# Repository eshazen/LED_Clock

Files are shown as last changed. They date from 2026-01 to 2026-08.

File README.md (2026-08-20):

# LED Clock

Yet another LED pseudo-analog clock.
<br>6 concentric circles of 60 LEDs plus one of 12 LEDs.
<br>Arduino Nano ESP32.

Current code (`clock_v3`) runs on 1Hz interrupts but expects
periodic time updates of the format `[hh:mm:ss]` at 1200 baud
from an external RTC.

First release code (`clock_v2`) just uses 1Hz timer interrupts
and provides hour / minute set buttons.

No ECOs on the PC board.  Forgot mounting holes though.
See `Case` folder for a two-part 3D printed wall hangar
with a little control panel for the set buttons.

Works OK but loses ~1min/day.  Need to work on the timekeeping.

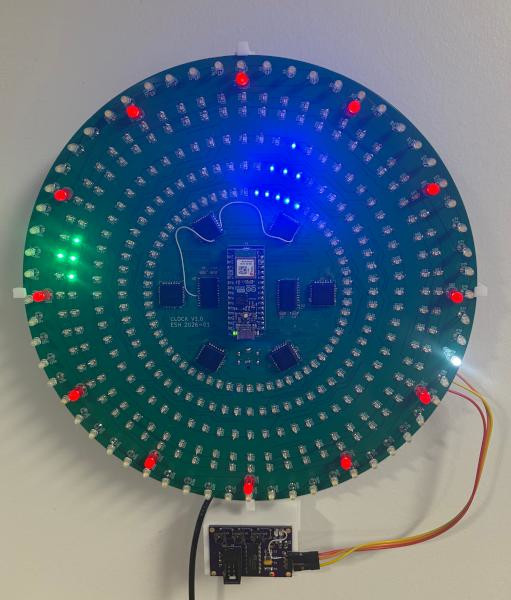
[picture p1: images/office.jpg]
Front View


### 2026-04-19

Implemented initial RTC board software.

### 2026-04-12

Working on SimpleRTC add-on to keep better time.
<br>Need a serial port on the ESP32.
<br>It's confusing:
https://forum.arduino.cc/t/nano-esp32-onboard-uart-and-pin-numbering-issues/1269099/9

I _think_ this should work:

    Serial1.begin(1200, SERIAL_8N1, D11, D12);

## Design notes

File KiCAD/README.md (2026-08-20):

# PCB designs

`Led_clock_sector` is the main PCB.  No errors I'm aware of.
The current version here has mounting holes which are missing
from the V1 as-built version.

`SimpleRTC` is a small board with RTC, MCU and pushbuttons.
The version here in git as of this writing is incomplete...
no doubt there is an un-committed update on a laptop somewhere.

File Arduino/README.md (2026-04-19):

# LED_Clock

New version `clock_v3` expects time-set data at 1200 baud
on D12.  Set string format `[hh:mm:ss]`.
Runs with timer interrups between set commands

Previous sketch `clock_v2` uses
set buttons.  Timekeeping just uses the
ESP32 timer interrupts.  Loses ~1m per day.

`led_test` is useful for debugging LED issues.

`clock_ntp` is an attempt to get the time from NPT
servers but doesn't work reliably.

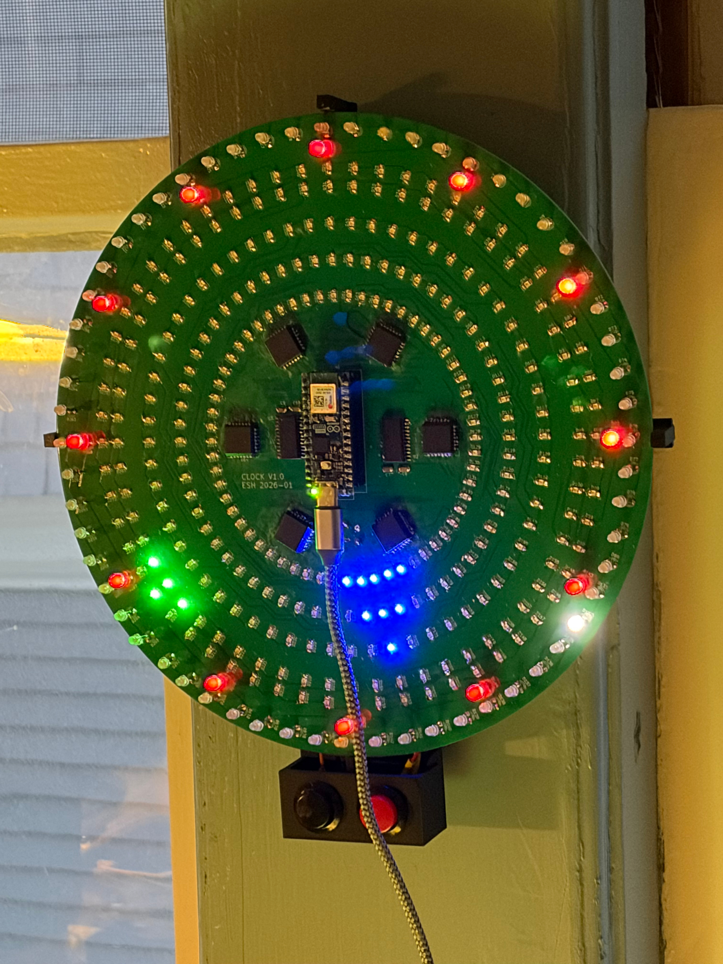
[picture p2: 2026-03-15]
images/front.jpg

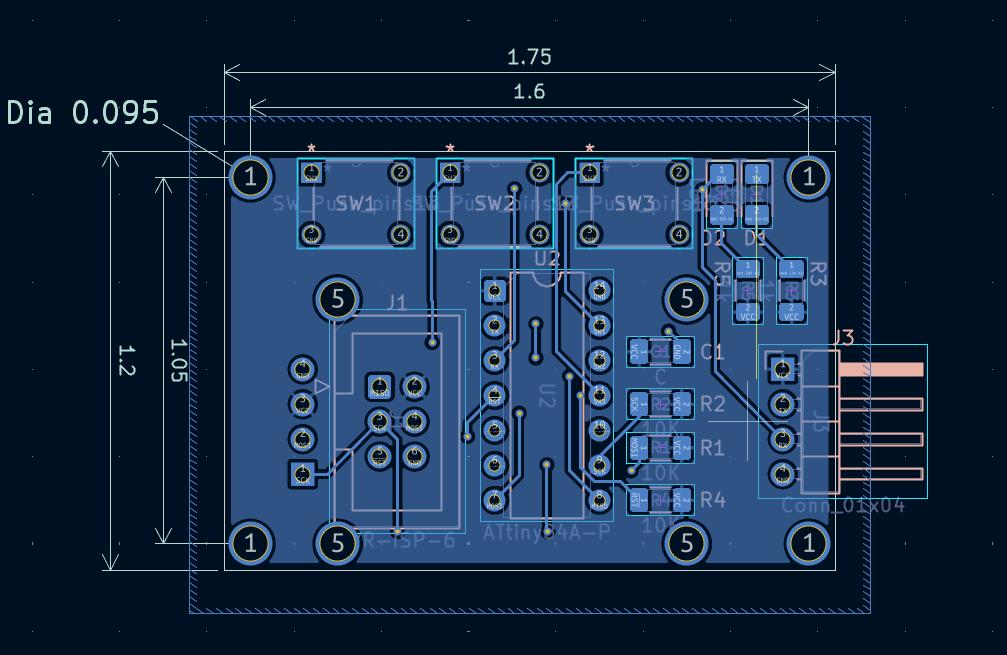
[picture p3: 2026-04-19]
Case/SimpleRTC_V1_Sketch.png

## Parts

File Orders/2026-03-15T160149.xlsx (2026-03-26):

Digi-Key: Shopping Cart
Index | Quantity | Part Number | Manufacturer Part Number | Description | Customer Reference | Available | Backorder | Unit Price | Extended Price USD
1 | 6 | 732-5013-ND | 151033RS03000 | LED RED CLEAR 3MM ROUND T/H | D1,D2 | 6 | 0 | 0.17 | 1.02
2 | 3 | A122759-ND | 1761681-1 | CONN HEADER VERT 6POS 2.54MM | J1 | 3 | 0 | 1.65 | 4.95
3 | 6 | 2057-PH1RB-04-UA-ND | PH1RB-04-UA | CONN HEADER R/A 4POS 2.54MM | J2 | 6 | 0 | 0.16 | 0.96
4 | 3 | ATTINY84A-PU-ND | ATTINY84A-PU | IC MCU 8BIT 8KB FLASH 14DIP | U2 | 3 | 0 | 1.62 | 4.86
5 | 10 | 450-1157-ND | FSM101 | SWITCH TACTILE SPST-NO 0.05A 24V |  | 10 | 0 | 0.382 | 3.82

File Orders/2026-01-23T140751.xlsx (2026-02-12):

Digi-Key: Shopping Cart
Index | Quantity | Part Number | Manufacturer Part Number | Description | Customer Reference | Available | Backorder | Unit Price | Extended Price USD
1 | 10 | 1516-QBL7IW60D-NW-ND | QBL7IW60D-NW | LED WHITE DIFFUSED T-1 T/H |  | 10 | 0 | 0.41 | 4.10
2 | 5 | 732-5016-ND | 151051RS11000 | LED RED DIFFUSED 5MM ROUND T/H |  | 5 | 0 | 0.15 | 0.75
3 | 25 | 3147-B1A81NG--20C000313U1930CT-ND | B1A81NG--20C000313U1930 | LED GREEN CLEAR 1206 SMD |  | 25 | 0 | 0.12 | 3.00
4 | 30 | 3147-B1A81NB--20C000313U1930CT-ND | B1A81NB--20C000313U1930 | LED BLUE CLEAR 1206 SMD |  | 30 | 0 | 0.12 | 3.60

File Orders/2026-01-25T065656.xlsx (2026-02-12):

Digi-Key: Shopping Cart
Index | Quantity | Part Number | Manufacturer Part Number | Description | Customer Reference | Available | Backorder | Unit Price | Extended Price USD
1 | 1 | 1050-ABX00083-ND | ABX00083 | ARDUINO NANO ESP32 WITH HEADERS | A1 | 1 | 0 | 19.3 | 19.30
2 | 25 | 4713-GMC31X7R104K10NTCT-ND | GMC31X7R104K10NT | CAP1206 X7R .1UF 10% 10V | C1,C2,C3,C4,C5,C6,C7,C8,C9,C10 | 25 | 0 | 0.067 | 1.68
3 | 100 | 1516-QBL7IW60D-NW-ND | QBL7IW60D-NW | LED WHITE DIFFUSED T-1 T/H | D1,D2,D3,D4,D5,D6,D7,D8,D9,D10,D71,D72,D73,D74,D | 100 | 0 | 0.2963 | 29.63
4 | 20 | 732-5016-ND | 151051RS11000 | LED RED DIFFUSED 5MM ROUND T/H | D11,D12,D81,D82,D143,D144,D205,D206,D267,D268,D3 | 20 | 0 | 0.15 | 3.00
5 | 140 | 3147-B1A81NG--20C000313U1930CT-ND | B1A81NG--20C000313U1930 | LED GREEN CLEAR 1206 SMD | D21,D22,D23,D24,D25,D26,D27,D28,D29,D30,D31,D32, | 140 | 0 | 0.12 | 16.80
6 | 200 | 3147-B1A81NB--20C000313U1930CT-ND | B1A81NB--20C000313U1930 | LED BLUE CLEAR 1206 SMD | D41,D42,D43,D44,D45,D46,D47,D48,D49,D50,D51,D52, | 200 | 0 | 0.12 | 24.00
7 | 1 | CP-082BHCT-ND | PJ-082BH | CONN PWR JACK 2.5X5.5MM SOLDER | J2 | 1 | 0 | 1.78 | 1.78
8 | 1 | A120356-ND | 1-2199300-2 | CONN IC DIP SOCKET 32POS TINLEAD | N1 | 1 | 0 | 0.92 | 0.92
9 | 10 | ICM7218AIQI+-ND | ICM7218AIQI+ | IC DRVR 7 SEGMNT 8 DIGIT 28PLCC | U1,U51,U52,U53,U54,U55 | 10 | 0 | 12.616 | 126.16
10 | 2 | 296-14911-1-ND | SN74LVC4245ADWR | IC XLTR VL BIDIR 24-SOIC | U2,U3 | 2 | 0 | 1.79 | 3.58

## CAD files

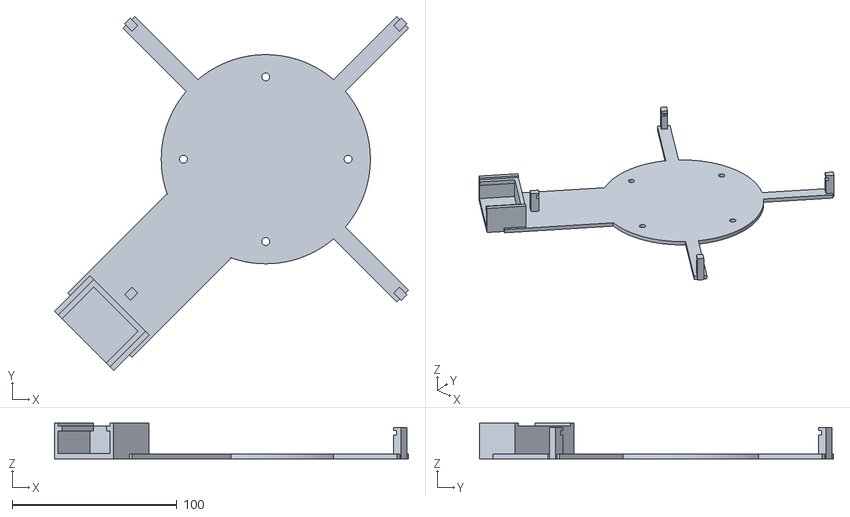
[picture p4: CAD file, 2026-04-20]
Case/plate2.stl
215.0 x 215.0 x 21.6

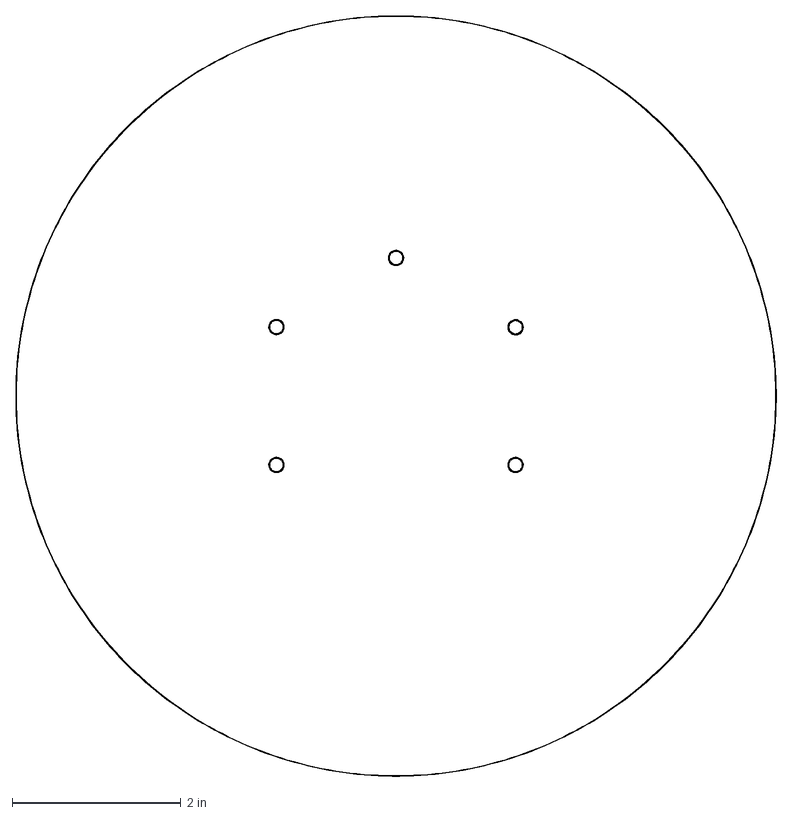
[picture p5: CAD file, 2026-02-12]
KiCAD/Led_clock_sector/DXF/Led_clock_sector-User_3.dxf
9.00 x 9.00 in

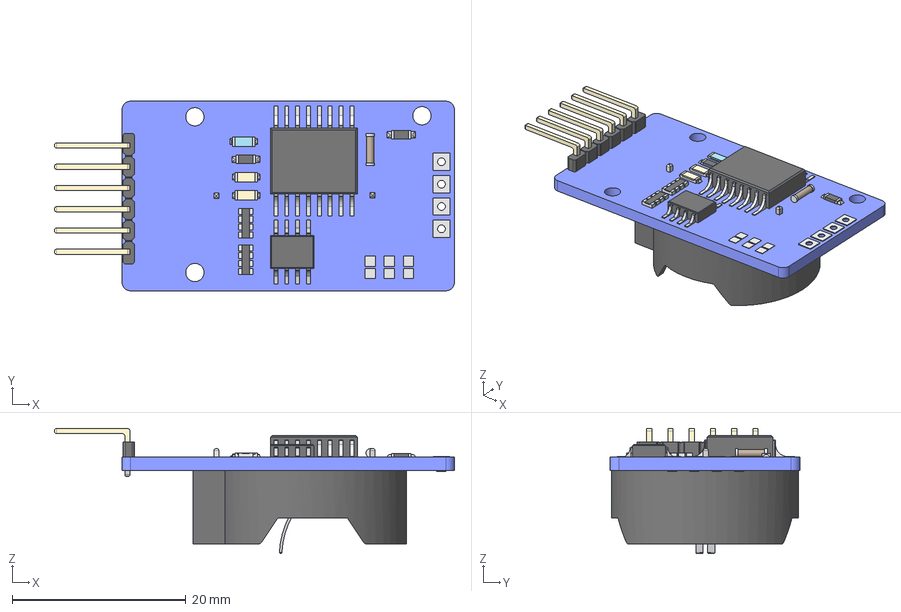
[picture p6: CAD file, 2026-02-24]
KiCAD/SimpleRTC/HW-84 v7.step
46.1 x 21.9 x 14.4 mm

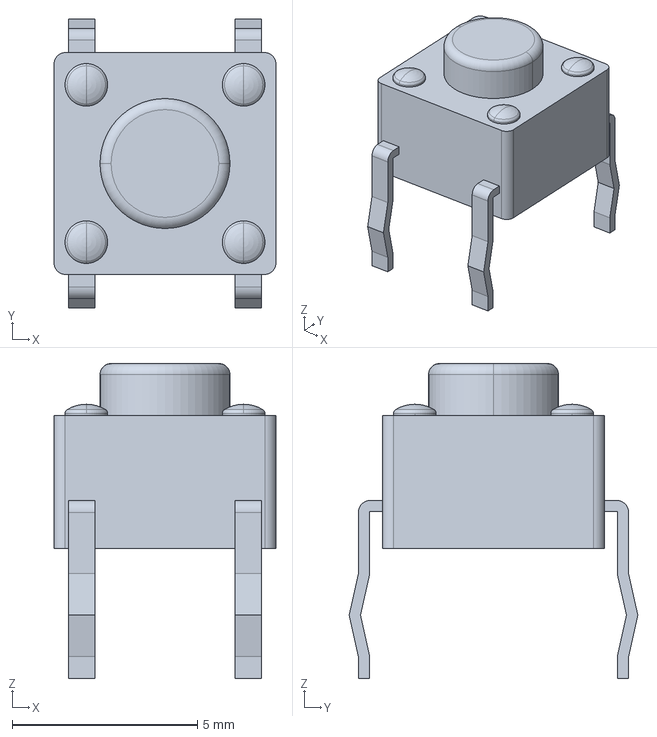
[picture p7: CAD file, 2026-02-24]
KiCAD/SimpleRTC/models/c-1825910-6-c-3d.stp
5.99 x 7.80 x 8.51 mm

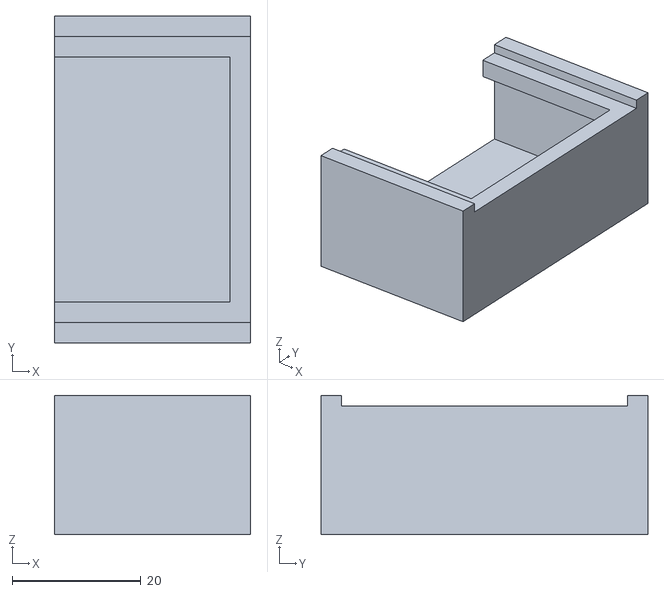
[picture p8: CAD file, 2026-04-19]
Case/test.stl
30.5 x 50.8 x 21.6

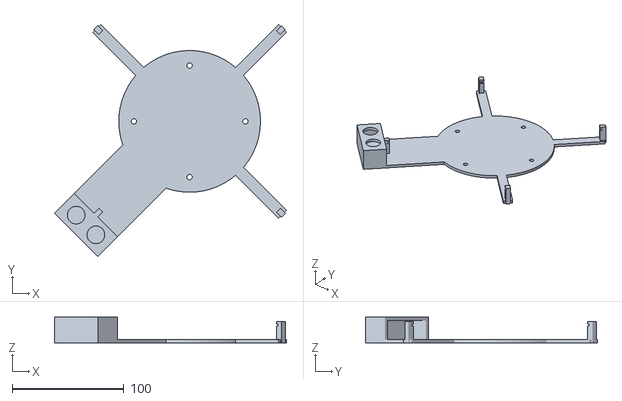
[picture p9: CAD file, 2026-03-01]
Case/plate.stl
208.1 x 208.1 x 23.0

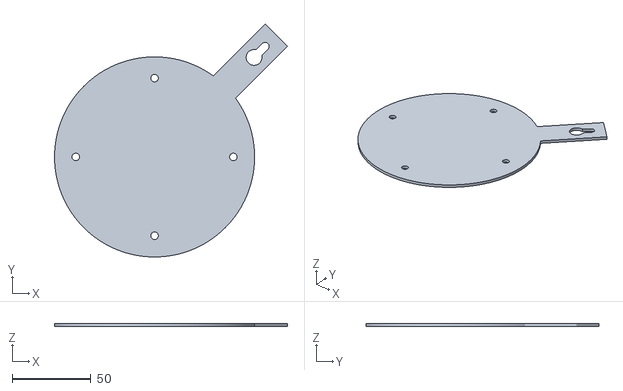
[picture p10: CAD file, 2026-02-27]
Case/hangar.stl
147.9 x 147.9 x 2.00

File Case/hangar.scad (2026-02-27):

//
// hangar for clock
//

mm = 25.4;
e = 0.1;
$fn = 128;

pcb_dia = 9*mm;
plate_dia = 5*mm;
plate_thk = 2;

h_wid = 20;
h_len = 0;

slot_up = 1*mm;

module plate() {
  cylinder( h=plate_thk, d=plate_dia);
}

rotate( [0, 0, 45]) {
  difference() {
    plate();
    for( a=[0:90:270]) {
      rotate( [0, 0, a+45])
	translate( [50, 0, -e])
	cylinder( h=plate_thk+2*e, d=0.188*mm);
    }
  }
}

rotate( [0, 0, -45])
difference() {
  translate( [-h_wid/2, plate_dia/2-5, 0])
    cube( [h_wid, (pcb_dia-plate_dia)/2+h_len, plate_thk]);
  translate( [0, pcb_dia/2+h_len-25, -1]) {
    cylinder( d=10, h=5);
    translate( [0, 10, 0])
      cylinder( d=5, h=5);
    translate( [-2.5, 0, 0])
      cube( [5, 10, 5]);
  }
}

// translate( [0, 0, slot_up-1.6]) color("green") cylinder( h=1.6, d=pcb_dia);
// translate( [0, 0, slot_up-1.6]) % cylinder( h=1.6, d=pcb_dia);

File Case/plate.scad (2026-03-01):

mm = 25.4;
e = 0.1;
$fn = 128;

pcb_dia = 9*mm;
plate_dia = 5*mm;
plate_thk = 3;

clip_height = 0.75*mm;
slot_up = clip_height - 2;
groove_wid = 2.0;
groove_off = 1.6;
groove_dep = 2.2;
clip_wid = 0.25*mm;

clip_thk = 5;
spoke_wid = 10;

// button panel
bp_up = 20;
bp_wid = 55;
bp_len = 25;

bp_dia = 0.625*mm;

pcb_cor = clip_wid/2-groove_off;

module clip() {
  rotate( [0, 0, 180])
  translate( [-clip_wid/2, -clip_thk/2, 0]) {
    difference() {
      cube( [clip_wid, clip_thk, clip_height]);
      translate( [clip_wid-groove_dep, -e, slot_up-groove_wid])
	cube( [clip_wid, clip_thk+2*e, groove_wid]);
    }
  }
}

module plate() {
  cylinder( h=plate_thk, d=plate_dia);
  for( a=[0:90:270]) {  
    rotate( [0, 0, a])
      if( a == 180) {
	translate( [plate_dia/2-1, -bp_wid/2, 0]) {
	  cube( [pcb_dia/2+pcb_cor-plate_dia/2+3+bp_len, bp_wid, plate_thk]);
	  translate( [-5, 0, 0])
	    cube( [5.1, bp_wid, plate_thk]);
	}
      } else {
	translate( [plate_dia/2-1, -spoke_wid/2, 0])
	  cube( [pcb_dia/2+pcb_cor-plate_dia/2+3, spoke_wid, plate_thk]);
      }
  }
}

module bpanel() {
  difference() {
    translate( [bp_len, -bp_wid/2, 0]) {
      cube( [plate_thk, bp_wid, bp_up]);
      translate( [-bp_len+plate_thk, 0, bp_up]) {
	cube( [bp_len, bp_wid, plate_thk]);
	translate( [0, 0, -bp_up])
	  cube( [bp_len, plate_thk, bp_up+e]);
	translate( [0, bp_wid-plate_thk, -bp_up+e])
	  cube( [bp_len, plate_thk, bp_up+e]);
      }
    }
    translate( [bp_len/2+3, -bp_len/2, 5])
      cylinder( d=bp_dia, h=30);
    translate( [bp_len/2+3, bp_len/2, 5])
      cylinder( d=bp_dia, h=30);
  }
}


rotate( [0, 0, 45]) {
  difference() {
    plate();
    for( a=[0:90:270]) {
      rotate( [0, 0, a+45])
	translate( [50, 0, -e])
	cylinder( h=plate_thk+2*e, d=0.188*mm);
    }
  }
  for( a=[0:90:270]) {
    rotate( [0, 0, a]) {
      translate( [pcb_dia/2+pcb_cor, 0, 0]) {
	clip();
	if( a == 180) {
	  bpanel();
	}
      }
    }
  }
}

// translate( [0, 0, slot_up-1.6]) color("green") cylinder( h=1.6, d=pcb_dia);
// translate( [0, 0, slot_up-1.6]) % cylinder( h=1.6, d=pcb_dia);

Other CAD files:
Case/plate2.scad

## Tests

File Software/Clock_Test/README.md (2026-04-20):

Provide real-time clock support for various clocks (including the round LED_Clock).
Initialize and read a DS3231 RTC.

Look for button presses to update H, M, S at 5Hz.  When update seen,
reset the DS3231 and send a time string '[hh:mm:ss]' to serial port
at 1200 baud.

The S button resets the seconds to 0

Send a time update every 10s regardless of setting.

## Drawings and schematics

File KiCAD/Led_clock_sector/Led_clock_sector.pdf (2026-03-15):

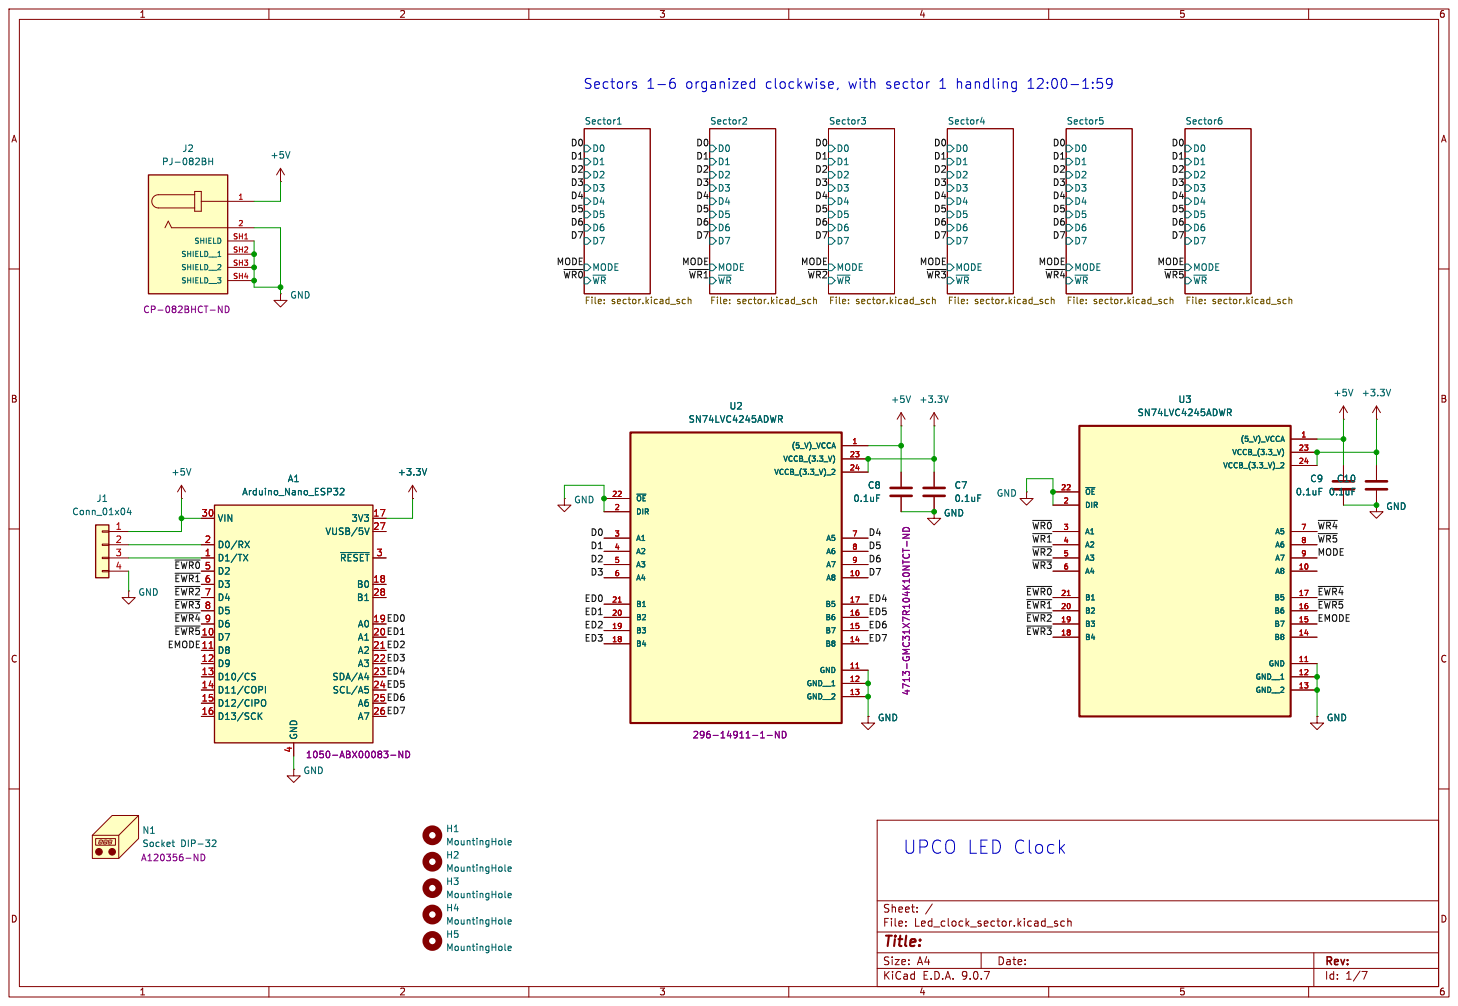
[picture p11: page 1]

~{WR} Sector2 File: sector.kicad_sch D0 D1 D2 D3 D4 D5 D6 D7 MODE

~{WR} Sector5 File: sector.kicad_sch D0 D1 D2 D3 D4 D5 D6 D7 MODE

~{WR} Sector4 File: sector.kicad_sch D0 D1 D2 D3 D4 D5 D6 D7 MODE

~{WR} Sector6 File: sector.kicad_sch GND

+3.3V A1 Arduino_Nano_ESP32
3V3 17 VUSB/5V 27 ~{RESET}3 B0 18 B1 28 A0 19 A1 20 A2 21 A3 22 SDA/A4 23 SCL/A5 24 A6 25 A7 26 A1 Arduino_Nano_ESP32

Id: 1/7 Title: File: Led_clock_sector.kicad_sch Sheet: /

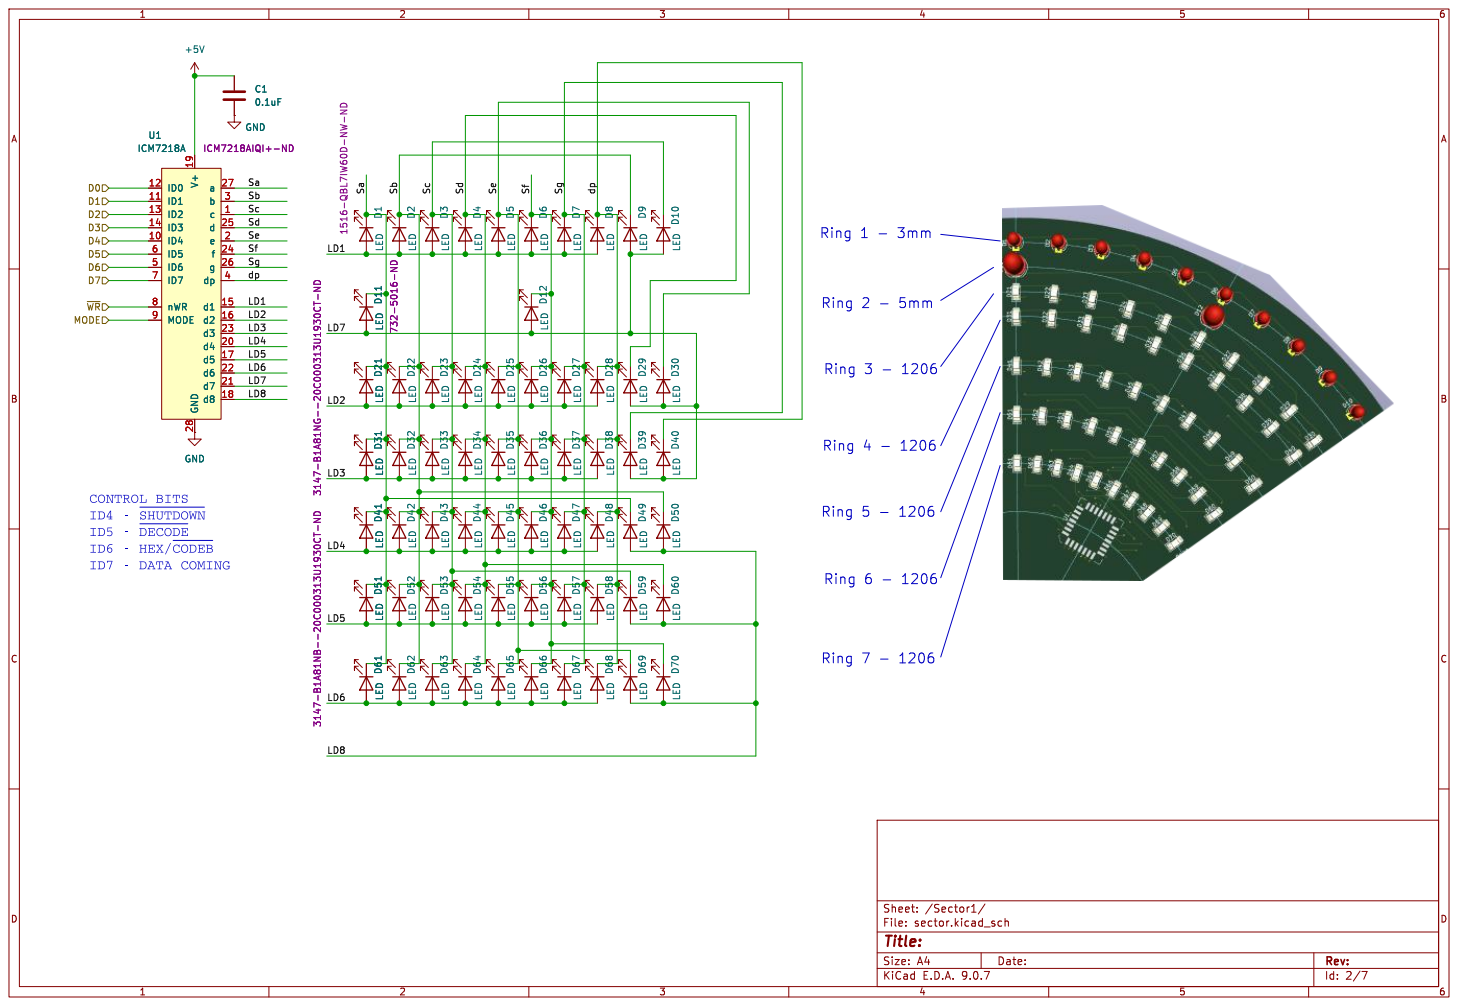
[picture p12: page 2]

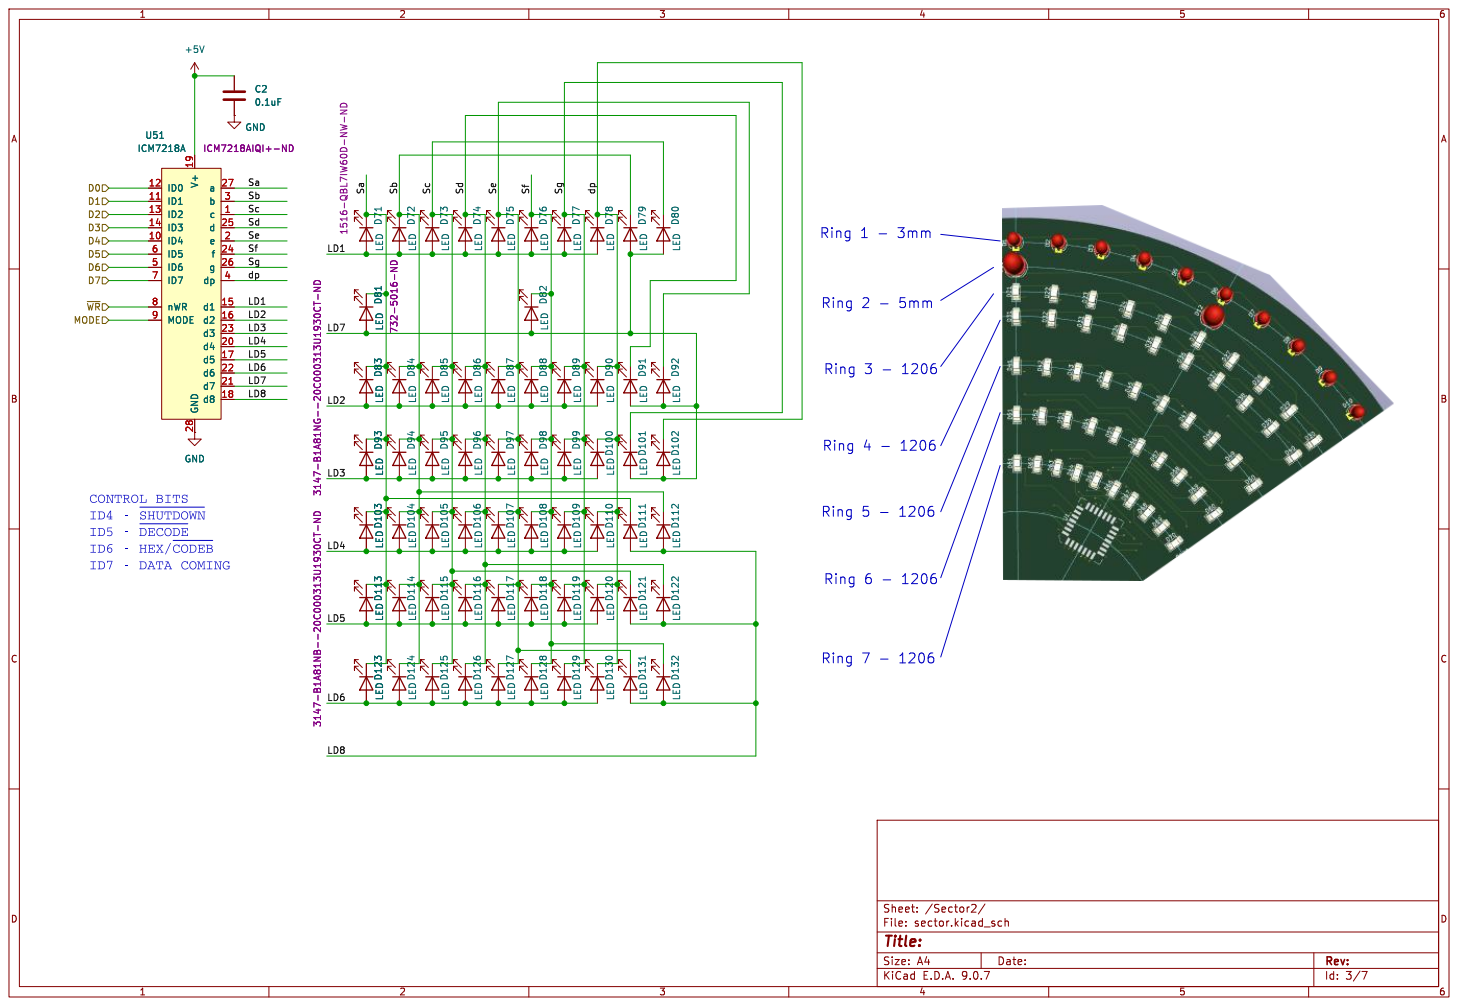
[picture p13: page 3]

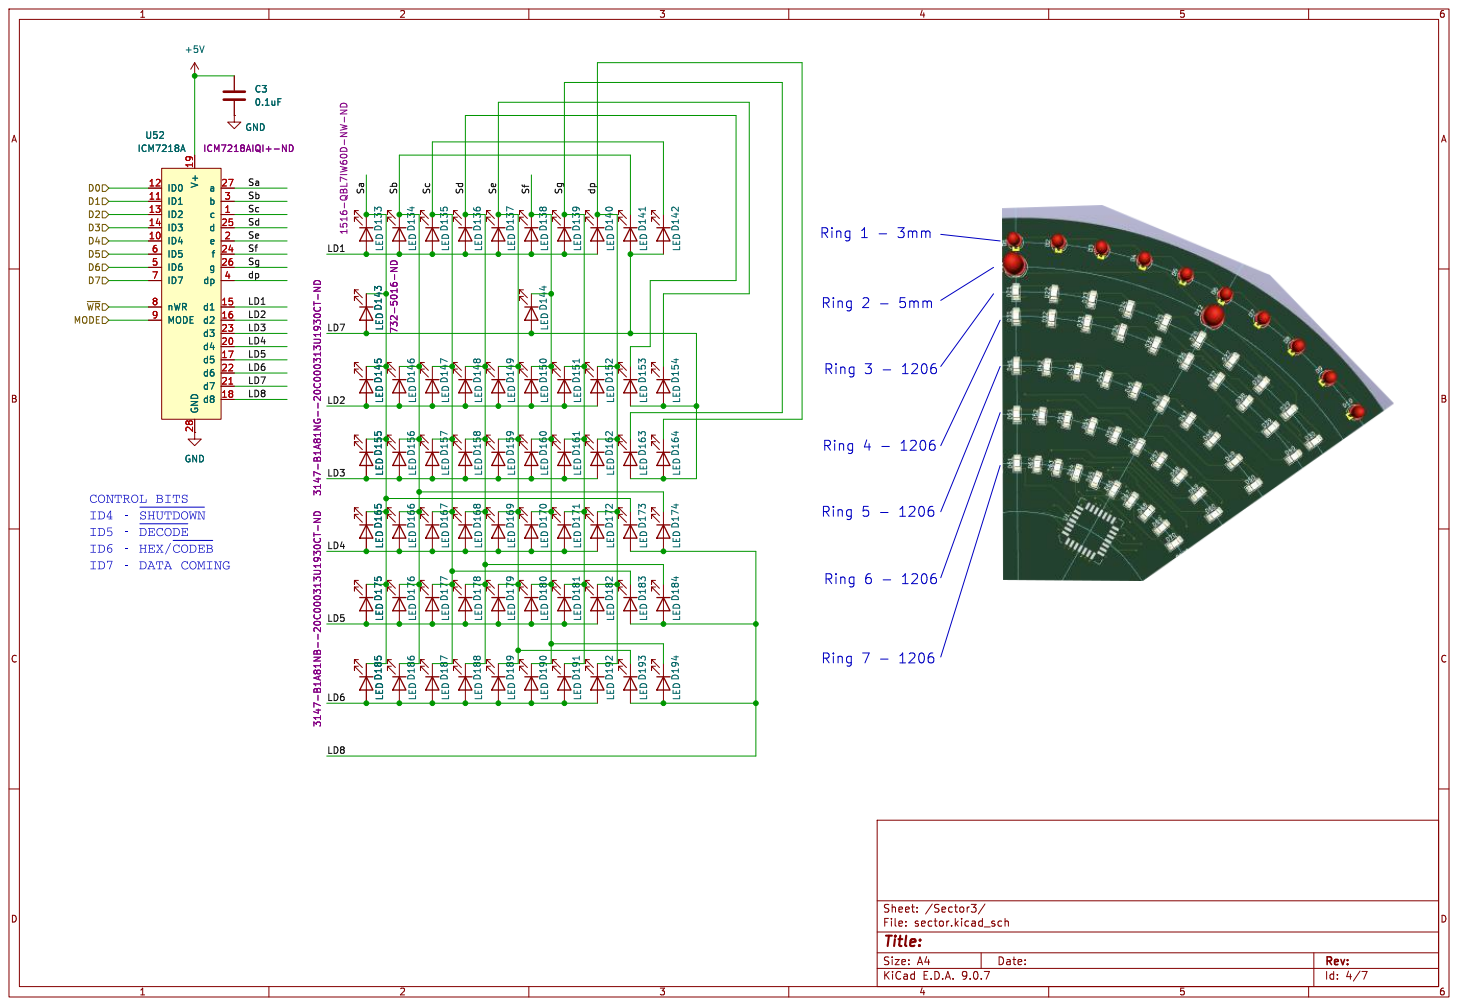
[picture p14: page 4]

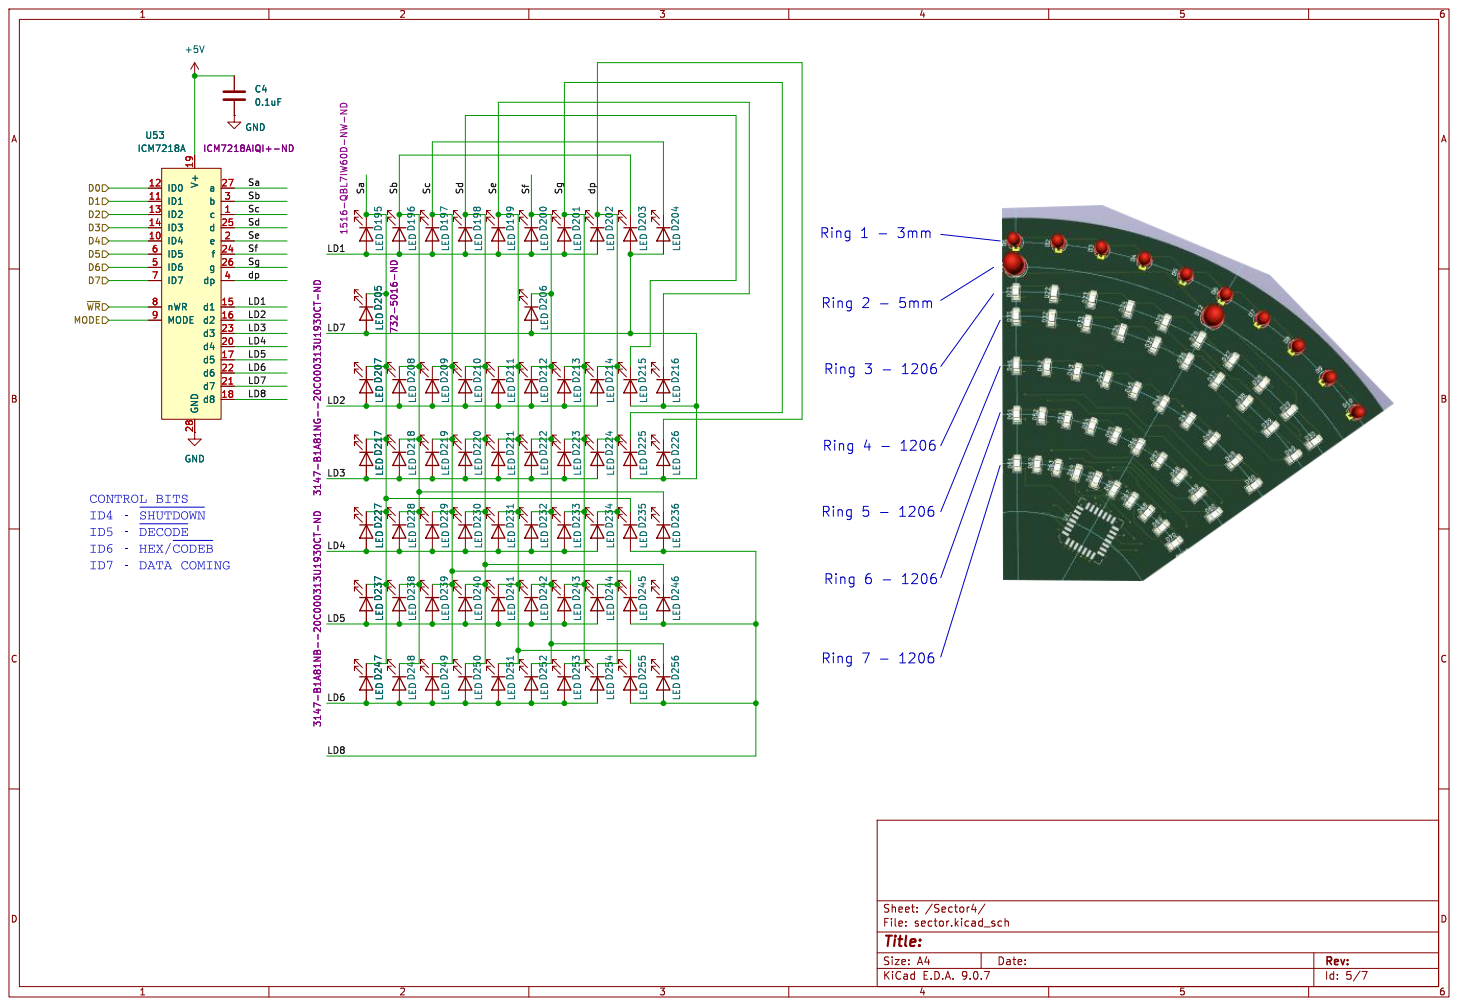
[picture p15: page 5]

Ring 6 - 1206 D247 LED D227 LED 3147-B1A81NB--20C000313U1930CT-ND

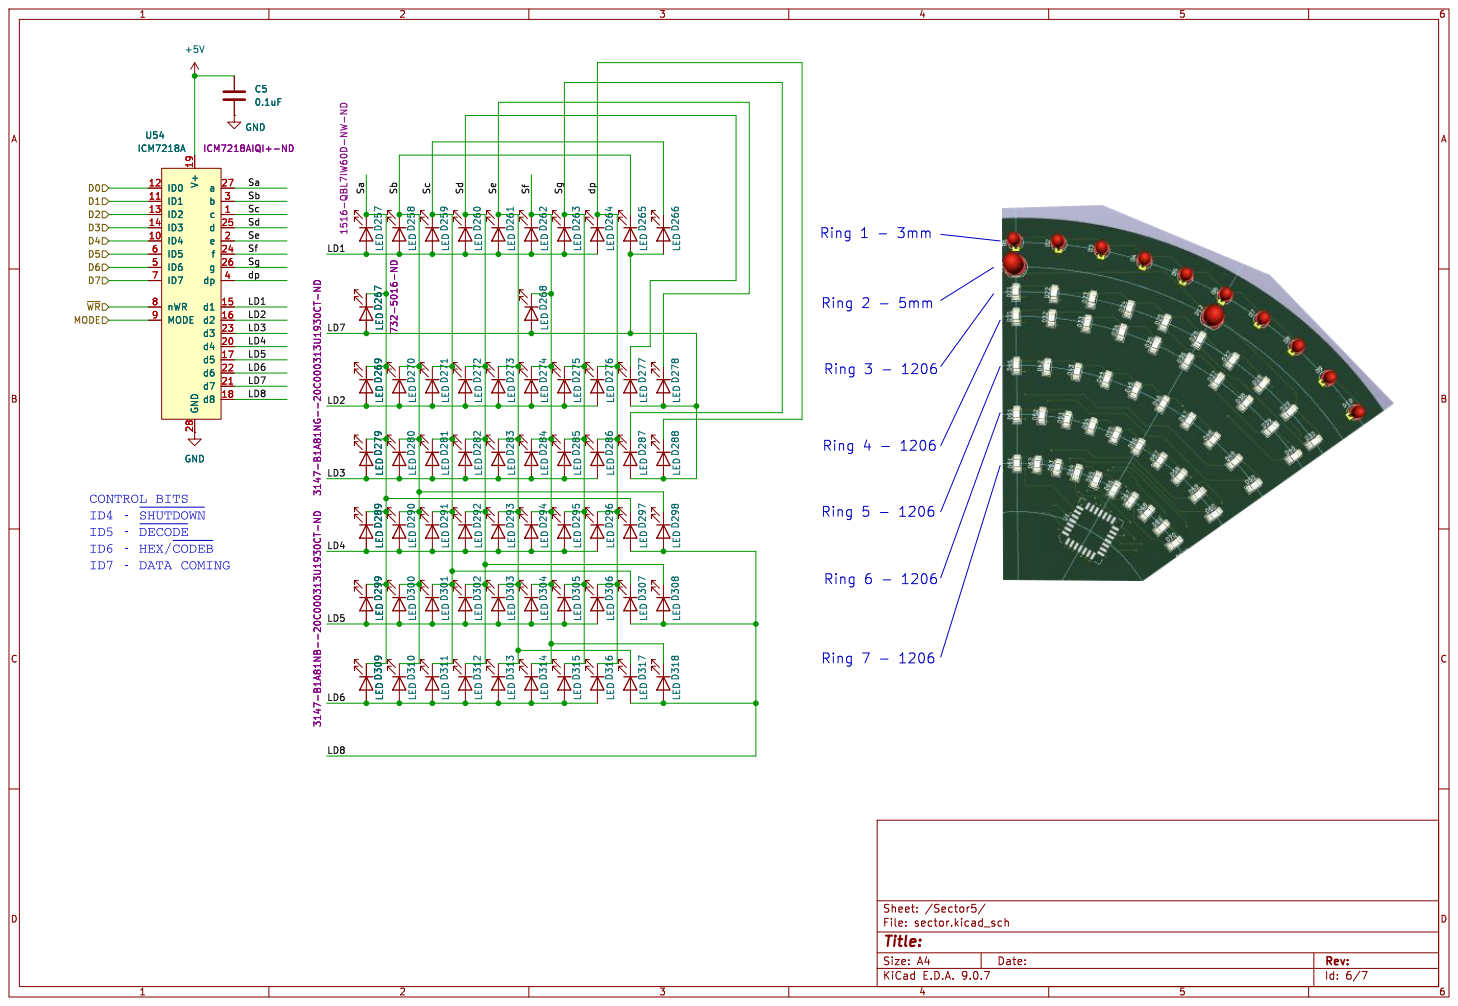
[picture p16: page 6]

Ring 6 - 1206 D309 LED D289 LED 3147-B1A81NB--20C000313U1930CT-ND

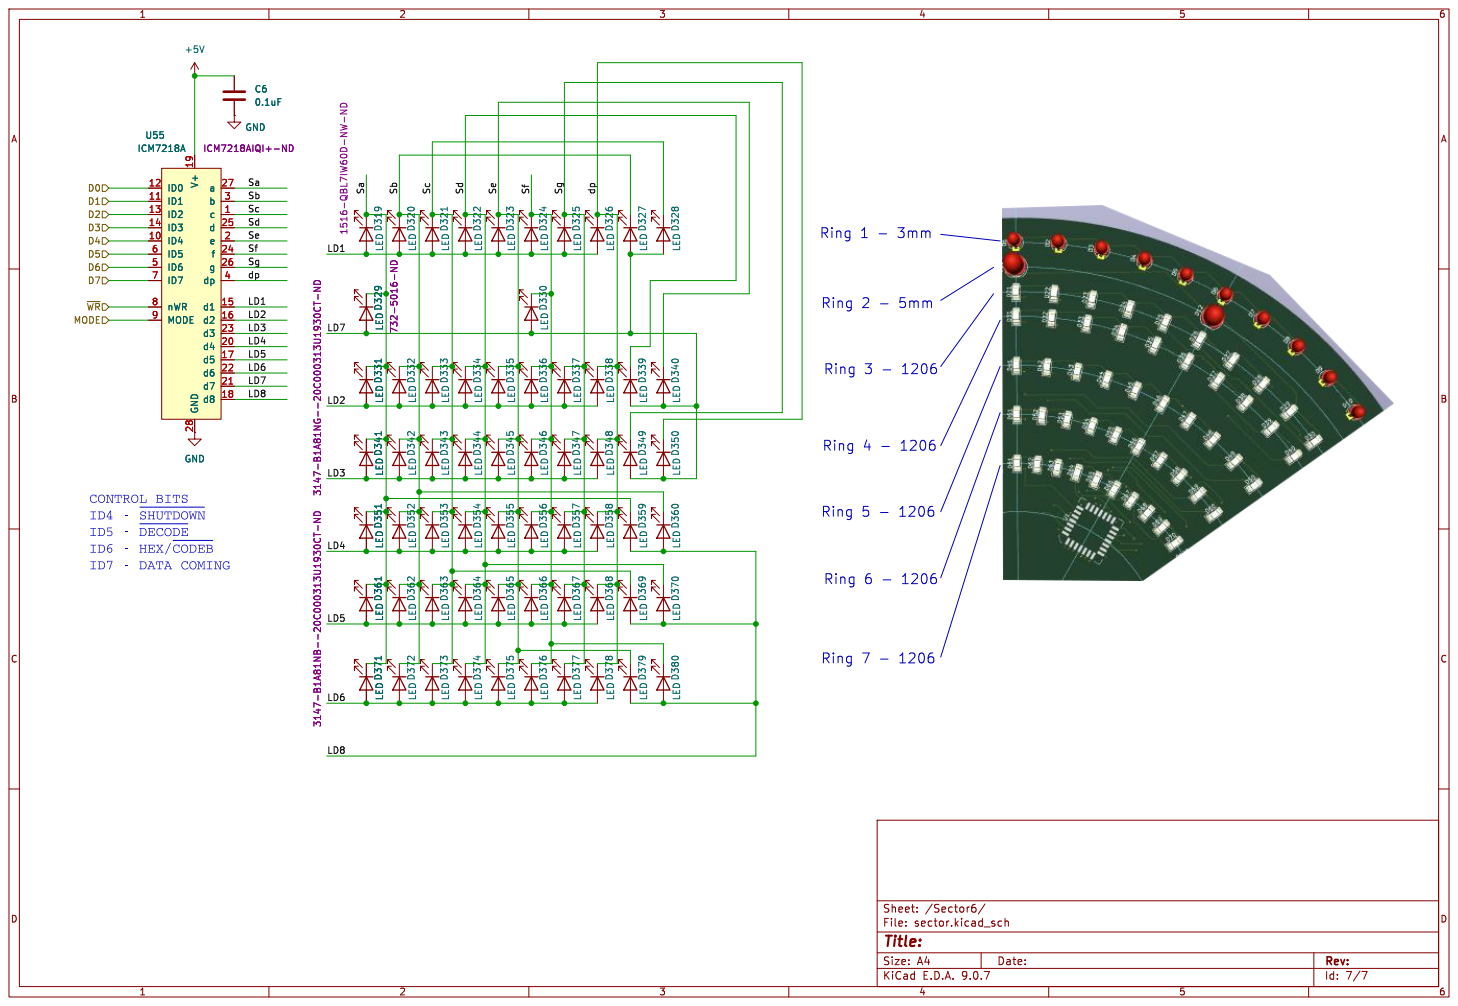
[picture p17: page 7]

Ring 6 - 1206 D371 LED D351 LED 3147-B1A81NB--20C000313U1930CT-ND

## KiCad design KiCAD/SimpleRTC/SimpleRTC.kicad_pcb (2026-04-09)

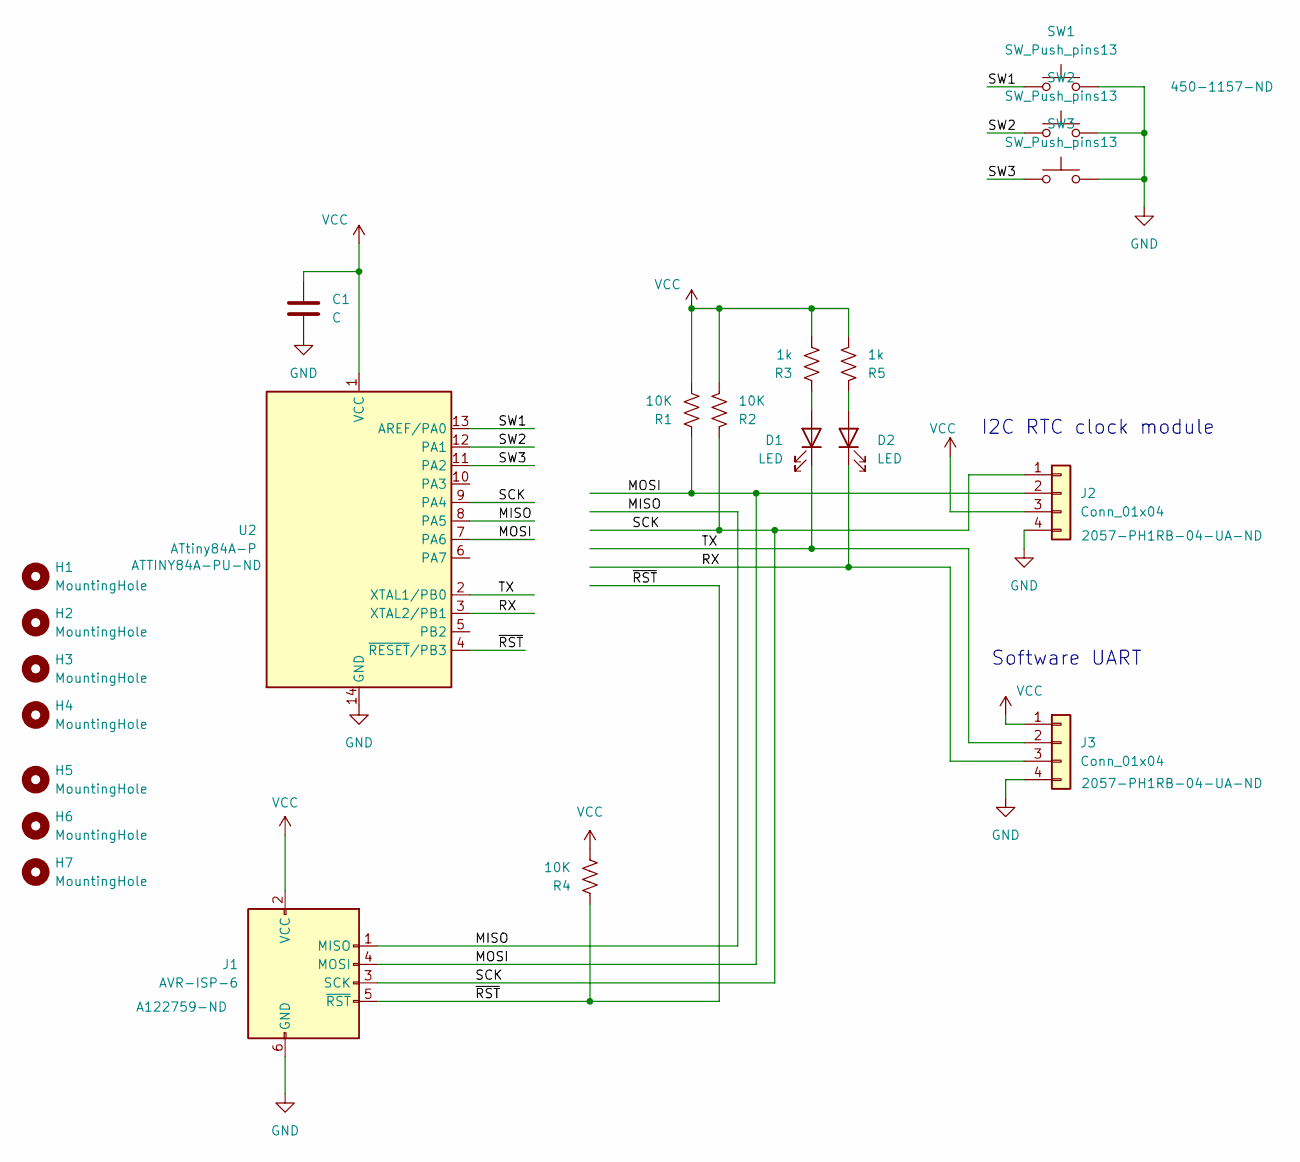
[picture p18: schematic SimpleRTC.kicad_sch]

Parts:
C1: C; C_1206_3216Metric_Pad1.33x1.80mm_HandSolder
D1, D2: LED; LED_1206_3216Metric_Pad1.42x1.75mm_HandSolder
H1, H2, H3, H4, H5, H6, H7: MountingHole; mtg_hole_256
J1: AVR-ISP-6; IDC-Header_2x03_P2.54mm_Vertical
J2: Conn_01x04; RTC_module
J3: Conn_01x04; PinHeader_1x04_P2.54mm_Horizontal
R1, R2, R4: 10K; R_1206_3216Metric_Pad1.30x1.75mm_HandSolder; DIGIKEY CF14JT10K0CT-ND
R3, R5: 1k; R_1206_3216Metric_Pad1.30x1.75mm_HandSolder; DIGIKEY CF14JT10K0CT-ND
SW1, SW2, SW3: SW_Push_pins13; SW_1437565-3
U2: ATtiny84A-P; DIP-14_W7.62mm

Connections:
/MISO: J1.1 (MISO), U2.8 (PA5)
/MOSI: J1.4 (MOSI), J2.2, R1.1, U2.7 (PA6)
/RX: D2.1 (K), J3.3, U2.3 (XTAL2/PB1)
/SCK: J1.3 (SCK), J2.1, R2.1, U2.9 (PA4)
/SW1: SW1.1, U2.13 (AREF/PA0)
/SW2: SW2.1, U2.12 (PA1)
/SW3: SW3.1, U2.11 (PA2)
/TX: D1.1 (K), J3.2, U2.2 (XTAL1/PB0)
/~RST: J1.5 (~RST), R4.1, U2.4 (~RESET/PB3)
GND: C1.2, J1.6 (GND), J2.4, J3.4, SW1.3, SW2.3, SW3.3, U2.14 (GND)
unnamed: D1.2 (A), R3.1
unnamed: D2.2 (A), R5.1
VCC: C1.1, J1.2 (VCC), J2.3, J3.1, R1.2, R2.2, R3.2, R4.2, R5.2, U2.1 (VCC)

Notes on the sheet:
I2C RTC clock module
Software UART

Board: 2 copper layers, 22 parts (14 on the bottom side), 13 nets, no tracks yet.

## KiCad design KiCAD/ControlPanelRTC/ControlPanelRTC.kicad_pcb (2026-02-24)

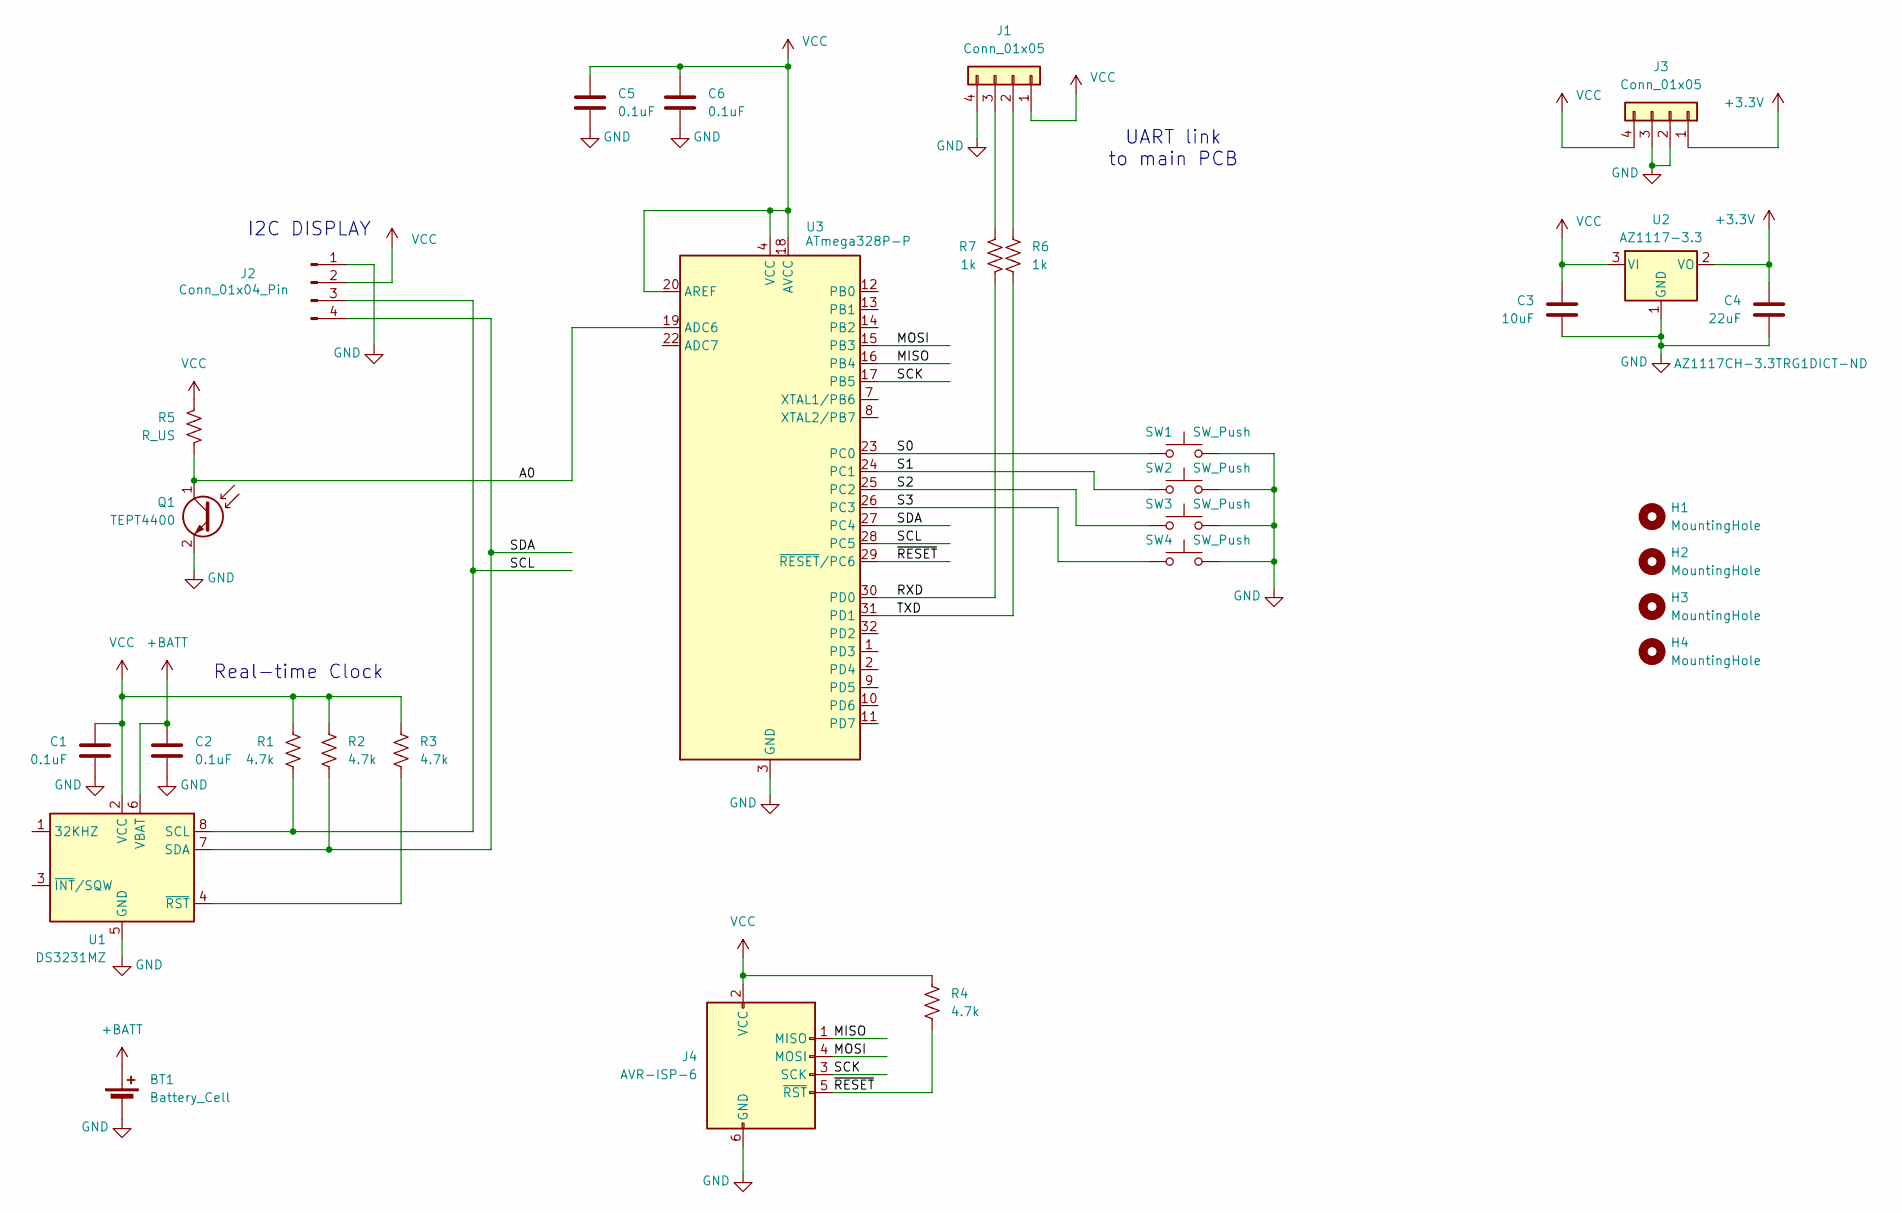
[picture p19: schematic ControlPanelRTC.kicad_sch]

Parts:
BT1: Battery_Cell; BatteryHolder_Keystone_3000_1x12mm
C1, C2, C5, C6: 0.1uF; C_1206_3216Metric_Pad1.33x1.80mm_HandSolder
C3: 10uF; C_1206_3216Metric_Pad1.33x1.80mm_HandSolder
C4: 22uF; C_1206_3216Metric_Pad1.33x1.80mm_HandSolder
H1, H2, H3, H4: MountingHole; mtg_440
J1, J3: Conn_01x05; PinHeader_1x04_P2.54mm_Horizontal
J2: Conn_01x04_Pin; OLED_0.96IN
J4: AVR-ISP-6; PinHeader_2x03_P2.54mm_Horizontal
Q1: TEPT4400; LED_D3.0mm_Clear
R1, R2, R3, R4: 4.7k; R_1206_3216Metric
R5: R_US; R_1206_3216Metric
R6, R7: 1k; R_1206_3216Metric
SW1, SW2, SW3, SW4: SW_Push; SW4_1825910-B_TEC
U1: DS3231MZ; SOIC-8_3.9x4.9mm_P1.27mm
U2: AZ1117-3.3; SOT-223-3_TabPin2
U3: ATmega328P-P; TQFP-32_7x7mm_P0.8mm

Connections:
+3.3V: C4.1, J3.1, U2.2 (VO)
+BATT: BT1.1 (+), C2.1, U1.6 (VBAT)
/A0: Q1.1 (C), R5.2, U3.19 (ADC6)
/MISO: J4.1 (MISO), U3.16 (PB4)
/MOSI: J4.4 (MOSI), U3.15 (PB3)
/RXD: R7.2, U3.30 (PD0)
/S0: SW1.1, U3.23 (PC0)
/S1: SW2.1, U3.24 (PC1)
/S2: SW3.1, U3.25 (PC2)
/S3: SW4.1, U3.26 (PC3)
/SCK: J4.3 (SCK), U3.17 (PB5)
/SCL: J2.3, R1.2, U1.8 (SCL), U3.28 (PC5)
/SDA: J2.4, R2.2, U1.7 (SDA), U3.27 (PC4)
/TXD: R6.2, U3.31 (PD1)
/~RESET: J4.5 (~RST), R4.2, U3.29 (~RESET/PC6)
GND: BT1.2 (-), C1.2, C2.2, C3.2, C4.2, C5.2, C6.2, J1.4, J2.1, J3.2, J3.3, J4.6 (GND), Q1.2 (E), SW1.3, SW2.3, SW3.3, SW4.3, U1.5 (GND), U2.1 (GND), U3.3 (GND), U3.5 (GND), U3.21 (GND)
unnamed: J1.2, R6.1
unnamed: J1.3, R7.1
unnamed: R3.2, U1.4 (~RST)
VCC: C1.1, C3.1, C5.1, C6.1, J1.1, J2.2, J3.4, J4.2 (VCC), R1.1, R2.1, R3.1, R4.1, R5.1, U1.2 (VCC), U2.3 (VI), U3.4 (VCC), U3.6 (VCC), U3.18 (AVCC), U3.20 (AREF)

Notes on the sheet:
UART link to main PCB
I2C DISPLAY
Real-time Clock

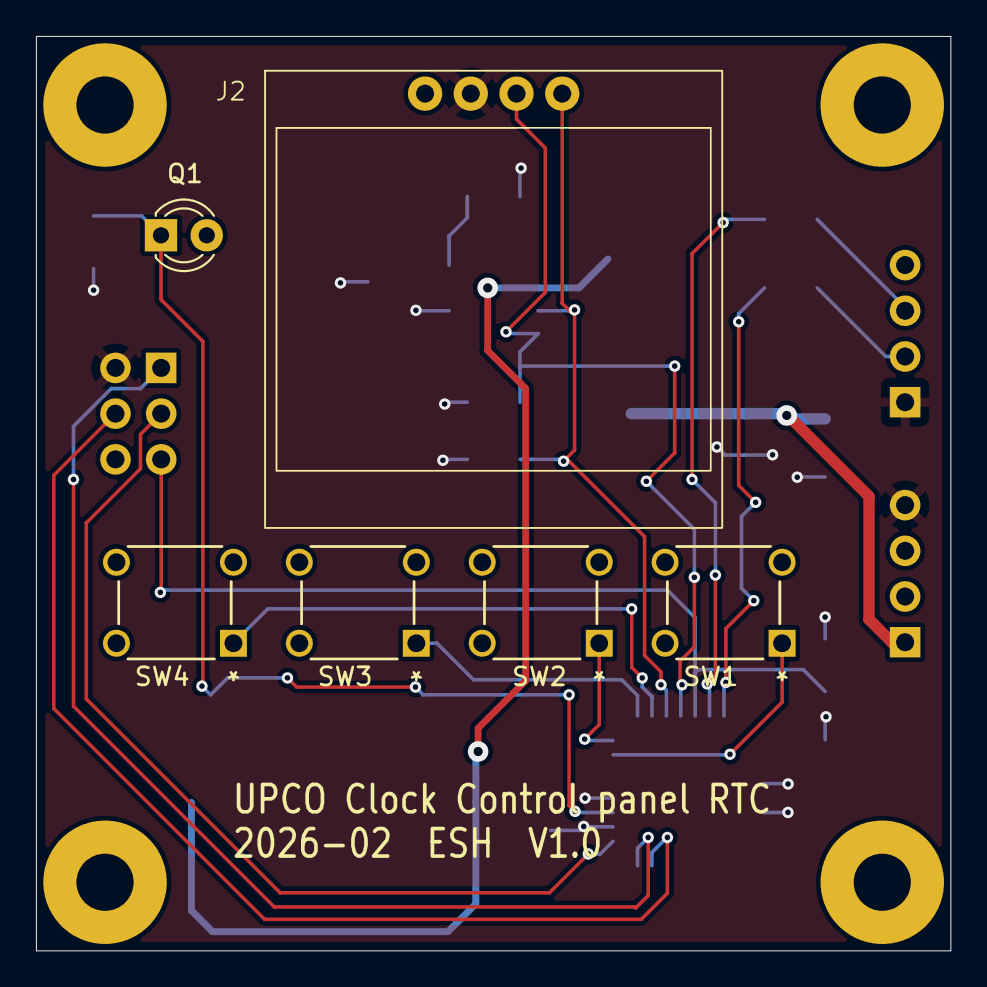
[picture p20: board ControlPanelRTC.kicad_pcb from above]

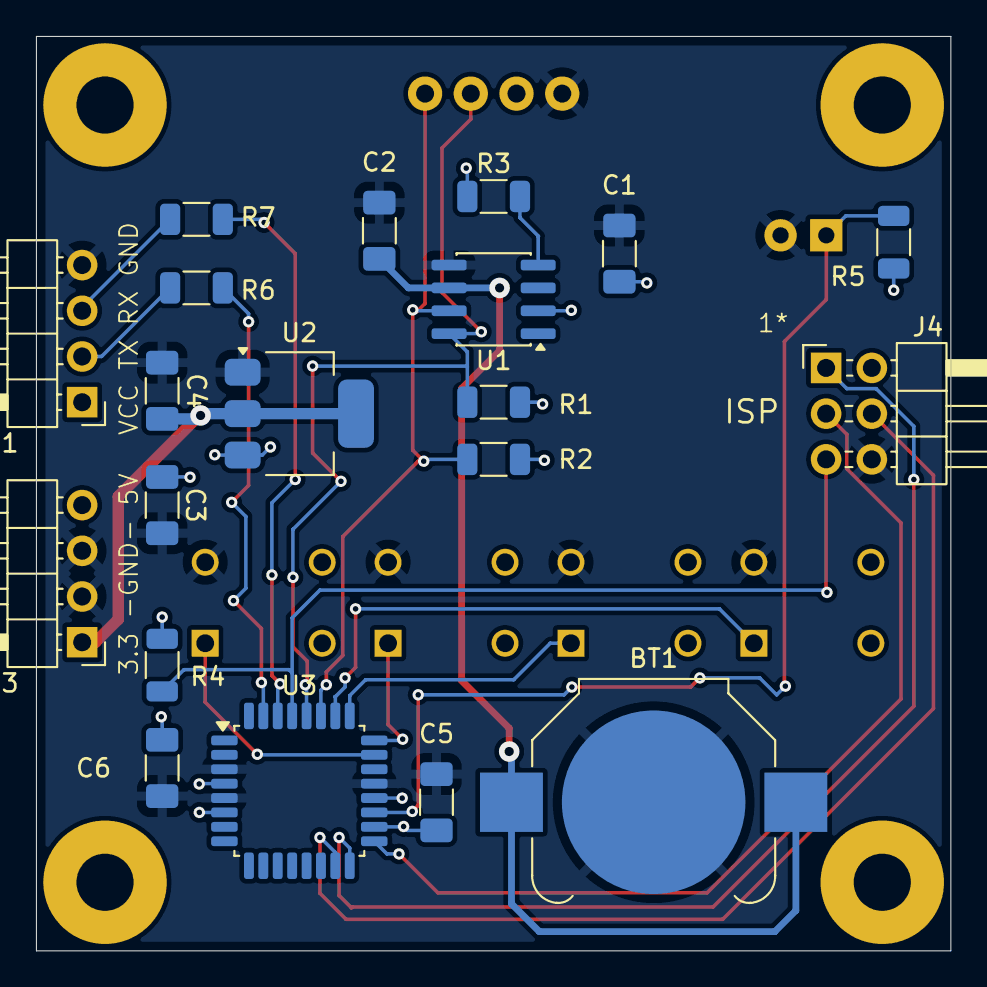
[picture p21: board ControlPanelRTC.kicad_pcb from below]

Board: 2 copper layers, 50.8 x 50.8 mm, 30 parts (20 on the bottom side), 20 nets.

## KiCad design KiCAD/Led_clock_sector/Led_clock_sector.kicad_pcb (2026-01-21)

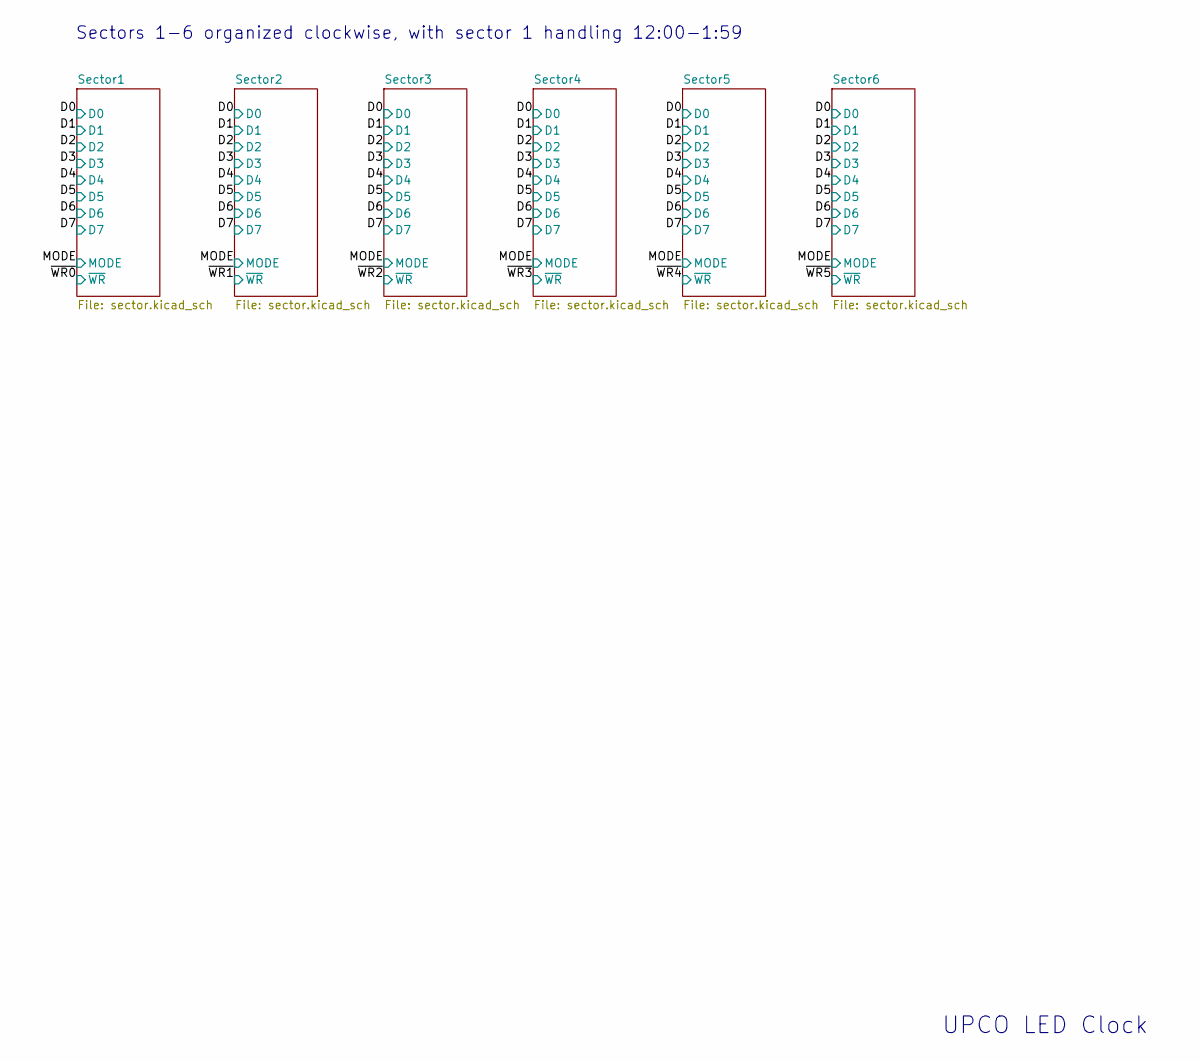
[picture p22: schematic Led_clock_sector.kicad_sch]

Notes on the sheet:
Sectors 1-6 organized clockwise, with sector 1 handling 12:00-1:59
UPCO LED Clock

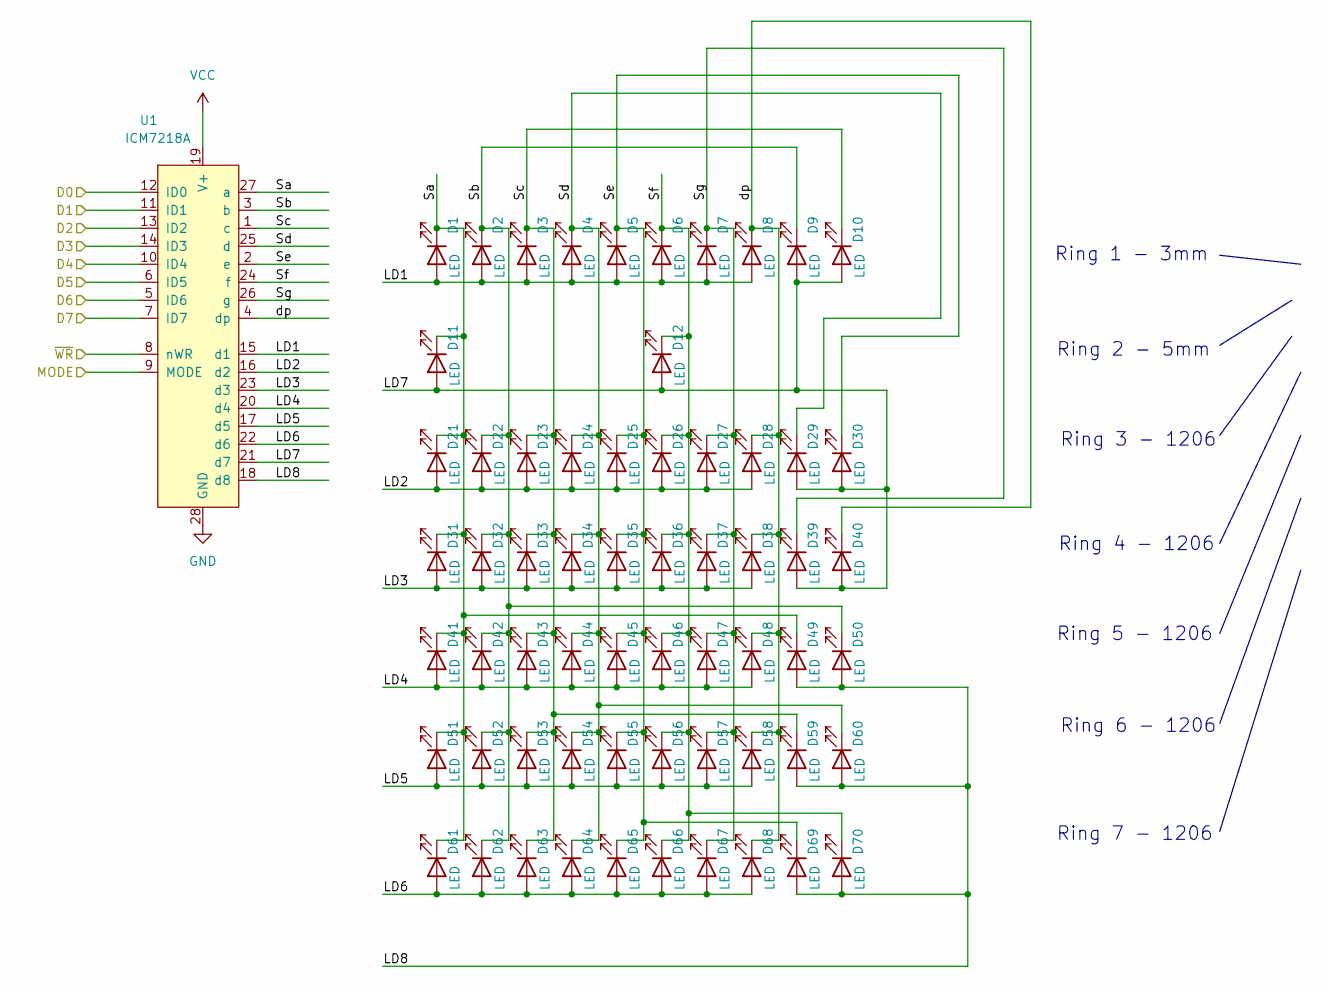
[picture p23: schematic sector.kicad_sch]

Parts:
D1, D2, D3, D4, D5, D6, D7, D8, D9, D10: LED; LED_D3.0mm
D11, D12: LED; LED_D5.0mm
D21, D22, D23, D24, D25, D26, D27, D28, D29, D30, D31, D32, D33, D34, D35, D36, D37, D38, D39, D40, D41, D42, D43, D44, D45, D46, D47, D48, D49, D50, D51, D52, D53, D54, D55, D56, D57, D58, D59, D60, D61, D62, D63, D64, D65, D66, D67, D68, D69, D70: LED; LED_1206_3216Metric_Pad1.42x1.75mm_HandSolder
U1: ICM7218A; PLCC-28

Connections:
/D0: U1.12 (ID0); also elsewhere on the board
/D1: U1.11 (ID1); also elsewhere on the board
/D2: U1.13 (ID2); also elsewhere on the board
/D3: U1.14 (ID3); also elsewhere on the board
/D4: U1.10 (ID4); also elsewhere on the board
/D5: U1.6 (ID5); also elsewhere on the board
/D6: U1.5 (ID6); also elsewhere on the board
/D7: U1.7 (ID7); also elsewhere on the board
/MODE: U1.9 (MODE); also elsewhere on the board
/Sector1/LD1: D1.2 (A), D2.2 (A), D3.2 (A), D4.2 (A), D5.2 (A), D6.2 (A), D7.2 (A), D8.2 (A), U1.15 (d1)
/Sector1/LD2: D21.2 (A), D22.2 (A), D23.2 (A), D24.2 (A), D25.2 (A), D26.2 (A), D27.2 (A), D28.2 (A), U1.16 (d2)
/Sector1/LD3: D31.2 (A), D32.2 (A), D33.2 (A), D34.2 (A), D35.2 (A), D36.2 (A), D37.2 (A), D38.2 (A), U1.23 (d3)
/Sector1/LD4: D41.2 (A), D42.2 (A), D43.2 (A), D44.2 (A), D45.2 (A), D46.2 (A), D47.2 (A), D48.2 (A), U1.20 (d4)
/Sector1/LD5: D51.2 (A), D52.2 (A), D53.2 (A), D54.2 (A), D55.2 (A), D56.2 (A), D57.2 (A), D58.2 (A), U1.17 (d5)
/Sector1/LD6: D61.2 (A), D62.2 (A), D63.2 (A), D64.2 (A), D65.2 (A), D66.2 (A), D67.2 (A), D68.2 (A), U1.22 (d6)
/Sector1/LD7: D9.2 (A), D10.2 (A), D11.2 (A), D12.2 (A), D29.2 (A), D30.2 (A), D39.2 (A), D40.2 (A), U1.21 (d7)
/Sector1/LD8: D49.2 (A), D50.2 (A), D59.2 (A), D60.2 (A), D69.2 (A), D70.2 (A), U1.18 (d8)
/Sector1/Sa: D1.1 (K), D11.1 (K), D21.1 (K), D31.1 (K), D41.1 (K), D49.1 (K), D51.1 (K), D61.1 (K), U1.27 (a)
/Sector1/Sb: D2.1 (K), D9.1 (K), D22.1 (K), D32.1 (K), D42.1 (K), D50.1 (K), D52.1 (K), D62.1 (K), U1.3 (b)
/Sector1/Sc: D3.1 (K), D10.1 (K), D23.1 (K), D33.1 (K), D43.1 (K), D53.1 (K), D59.1 (K), D63.1 (K), U1.1 (c)
/Sector1/Sd: D4.1 (K), D24.1 (K), D29.1 (K), D34.1 (K), D44.1 (K), D54.1 (K), D60.1 (K), D64.1 (K), U1.25 (d)
/Sector1/Se: D5.1 (K), D25.1 (K), D30.1 (K), D35.1 (K), D45.1 (K), D55.1 (K), D65.1 (K), D69.1 (K), U1.2 (e)
/Sector1/Sf: D6.1 (K), D12.1 (K), D26.1 (K), D36.1 (K), D46.1 (K), D56.1 (K), D66.1 (K), D70.1 (K), U1.24 (f)
/Sector1/Sg: D7.1 (K), D27.1 (K), D37.1 (K), D39.1 (K), D47.1 (K), D57.1 (K), D67.1 (K), U1.26 (g)
/Sector1/dp: D8.1 (K), D28.1 (K), D38.1 (K), D40.1 (K), D48.1 (K), D58.1 (K), D68.1 (K), U1.4 (dp)
/~WR0: U1.8 (nWR)
GND: U1.28 (GND); also elsewhere on the board
VCC: U1.19 (V+); also elsewhere on the board

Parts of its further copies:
D71, D72, D73, D74, D75, D76, D77, D78, D79, D80, D133, D134, D135, D136, D137, D138, D139, D140, D141, D142, D195, D196, D197, D198, D199, D200, D201, D202, D203, D204, D257, D258, D259, D260, D261, D262, D263, D264, D265, D266, D319, D320, D321, D322, D323, D324, D325, D326, D327, D328: LED; LED_D3.0mm
D81, D82, D143, D144, D205, D206, D267, D268, D329, D330: LED; LED_D5.0mm
D83, D84, D85, D86, D87, D88, D89, D90, D91, D92, D93, D94, D95, D96, D97, D98, D99, D100, D101, D102, D103, D104, D105, D106, D107, D108, D109, D110, D111, D112, D113, D114, D115, D116, D117, D118, D119, D120, D121, D122, D123, D124, D125, D126, D127, D128, D129, D130, D131, D132, D145, D146, D147, D148, D149, D150, D151, D152, D153, D154, D155, D156, D157, D158, D159, D160, D161, D162, D163, D164, D165, D166, D167, D168, D169, D170, D171, D172, D173, D174, D175, D176, D177, D178, D179, D180, D181, D182, D183, D184, D185, D186, D187, D188, D189, D190, D191, D192, D193, D194, D207, D208, D209, D210, D211, D212, D213, D214, D215, D216, D217, D218, D219, D220, D221, D222, D223, D224, D225, D226, D227, D228, D229, D230, D231, D232, D233, D234, D235, D236, D237, D238, D239, D240, D241, D242, D243, D244, D245, D246, D247, D248, D249, D250, D251, D252, D253, D254, D255, D256, D269, D270, D271, D272, D273, D274, D275, D276, D277, D278, D279, D280, D281, D282, D283, D284, D285, D286, D287, D288, D289, D290, D291, D292, D293, D294, D295, D296, D297, D298, D299, D300, D301, D302, D303, D304, D305, D306, D307, D308, D309, D310, D311, D312, D313, D314, D315, D316, D317, D318, D331, D332, D333, D334, D335, D336, D337, D338, D339, D340, D341, D342, D343, D344, D345, D346, D347, D348, D349, D350, D351, D352, D353, D354, D355, D356, D357, D358, D359, D360, D361, D362, D363, D364, D365, D366, D367, D368, D369, D370, D371, D372, D373, D374, D375, D376, D377, D378, D379, D380: LED; LED_1206_3216Metric_Pad1.42x1.75mm_HandSolder
U51, U52, U53, U54, U55: ICM7218A; PLCC-28

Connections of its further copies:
/D0: U51.12 (ID0), U52.12 (ID0), U53.12 (ID0), U54.12 (ID0), U55.12 (ID0); also elsewhere on the board
/D1: U51.11 (ID1), U52.11 (ID1), U53.11 (ID1), U54.11 (ID1), U55.11 (ID1); also elsewhere on the board
/D2: U51.13 (ID2), U52.13 (ID2), U53.13 (ID2), U54.13 (ID2), U55.13 (ID2); also elsewhere on the board
/D3: U51.14 (ID3), U52.14 (ID3), U53.14 (ID3), U54.14 (ID3), U55.14 (ID3); also elsewhere on the board
/D4: U51.10 (ID4), U52.10 (ID4), U53.10 (ID4), U54.10 (ID4), U55.10 (ID4); also elsewhere on the board
/D5: U51.6 (ID5), U52.6 (ID5), U53.6 (ID5), U54.6 (ID5), U55.6 (ID5); also elsewhere on the board
/D6: U51.5 (ID6), U52.5 (ID6), U53.5 (ID6), U54.5 (ID6), U55.5 (ID6); also elsewhere on the board
/D7: U51.7 (ID7), U52.7 (ID7), U53.7 (ID7), U54.7 (ID7), U55.7 (ID7); also elsewhere on the board
/MODE: U51.9 (MODE), U52.9 (MODE), U53.9 (MODE), U54.9 (MODE), U55.9 (MODE); also elsewhere on the board
/Sector2/LD1: D71.2 (A), D72.2 (A), D73.2 (A), D74.2 (A), D75.2 (A), D76.2 (A), D77.2 (A), D78.2 (A), U51.15 (d1)
/Sector2/LD2: D83.2 (A), D84.2 (A), D85.2 (A), D86.2 (A), D87.2 (A), D88.2 (A), D89.2 (A), D90.2 (A), U51.16 (d2)
/Sector2/LD3: D93.2 (A), D94.2 (A), D95.2 (A), D96.2 (A), D97.2 (A), D98.2 (A), D99.2 (A), D100.2 (A), U51.23 (d3)
/Sector2/LD4: D103.2 (A), D104.2 (A), D105.2 (A), D106.2 (A), D107.2 (A), D108.2 (A), D109.2 (A), D110.2 (A), U51.20 (d4)
/Sector2/LD5: D113.2 (A), D114.2 (A), D115.2 (A), D116.2 (A), D117.2 (A), D118.2 (A), D119.2 (A), D120.2 (A), U51.17 (d5)
/Sector2/LD6: D123.2 (A), D124.2 (A), D125.2 (A), D126.2 (A), D127.2 (A), D128.2 (A), D129.2 (A), D130.2 (A), U51.22 (d6)
/Sector2/LD7: D79.2 (A), D80.2 (A), D81.2 (A), D82.2 (A), D91.2 (A), D92.2 (A), D101.2 (A), D102.2 (A), U51.21 (d7)
/Sector2/LD8: D111.2 (A), D112.2 (A), D121.2 (A), D122.2 (A), D131.2 (A), D132.2 (A), U51.18 (d8)
/Sector2/Sa: D71.1 (K), D81.1 (K), D83.1 (K), D93.1 (K), D103.1 (K), D111.1 (K), D113.1 (K), D123.1 (K), U51.27 (a)
/Sector2/Sb: D72.1 (K), D79.1 (K), D84.1 (K), D94.1 (K), D104.1 (K), D112.1 (K), D114.1 (K), D124.1 (K), U51.3 (b)
/Sector2/Sc: D73.1 (K), D80.1 (K), D85.1 (K), D95.1 (K), D105.1 (K), D115.1 (K), D121.1 (K), D125.1 (K), U51.1 (c)
/Sector2/Sd: D74.1 (K), D86.1 (K), D91.1 (K), D96.1 (K), D106.1 (K), D116.1 (K), D122.1 (K), D126.1 (K), U51.25 (d)
/Sector2/Se: D75.1 (K), D87.1 (K), D92.1 (K), D97.1 (K), D107.1 (K), D117.1 (K), D127.1 (K), D131.1 (K), U51.2 (e)
/Sector2/Sf: D76.1 (K), D82.1 (K), D88.1 (K), D98.1 (K), D108.1 (K), D118.1 (K), D128.1 (K), D132.1 (K), U51.24 (f)
/Sector2/Sg: D77.1 (K), D89.1 (K), D99.1 (K), D101.1 (K), D109.1 (K), D119.1 (K), D129.1 (K), U51.26 (g)
/Sector2/dp: D78.1 (K), D90.1 (K), D100.1 (K), D102.1 (K), D110.1 (K), D120.1 (K), D130.1 (K), U51.4 (dp)
/Sector3/LD1: D133.2 (A), D134.2 (A), D135.2 (A), D136.2 (A), D137.2 (A), D138.2 (A), D139.2 (A), D140.2 (A), U52.15 (d1)
/Sector3/LD2: D145.2 (A), D146.2 (A), D147.2 (A), D148.2 (A), D149.2 (A), D150.2 (A), D151.2 (A), D152.2 (A), U52.16 (d2)
/Sector3/LD3: D155.2 (A), D156.2 (A), D157.2 (A), D158.2 (A), D159.2 (A), D160.2 (A), D161.2 (A), D162.2 (A), U52.23 (d3)
/Sector3/LD4: D165.2 (A), D166.2 (A), D167.2 (A), D168.2 (A), D169.2 (A), D170.2 (A), D171.2 (A), D172.2 (A), U52.20 (d4)
/Sector3/LD5: D175.2 (A), D176.2 (A), D177.2 (A), D178.2 (A), D179.2 (A), D180.2 (A), D181.2 (A), D182.2 (A), U52.17 (d5)
/Sector3/LD6: D185.2 (A), D186.2 (A), D187.2 (A), D188.2 (A), D189.2 (A), D190.2 (A), D191.2 (A), D192.2 (A), U52.22 (d6)
/Sector3/LD7: D141.2 (A), D142.2 (A), D143.2 (A), D144.2 (A), D153.2 (A), D154.2 (A), D163.2 (A), D164.2 (A), U52.21 (d7)
/Sector3/LD8: D173.2 (A), D174.2 (A), D183.2 (A), D184.2 (A), D193.2 (A), D194.2 (A), U52.18 (d8)
/Sector3/Sa: D133.1 (K), D143.1 (K), D145.1 (K), D155.1 (K), D165.1 (K), D173.1 (K), D175.1 (K), D185.1 (K), U52.27 (a)
/Sector3/Sb: D134.1 (K), D141.1 (K), D146.1 (K), D156.1 (K), D166.1 (K), D174.1 (K), D176.1 (K), D186.1 (K), U52.3 (b)
/Sector3/Sc: D135.1 (K), D142.1 (K), D147.1 (K), D157.1 (K), D167.1 (K), D177.1 (K), D183.1 (K), D187.1 (K), U52.1 (c)
/Sector3/Sd: D136.1 (K), D148.1 (K), D153.1 (K), D158.1 (K), D168.1 (K), D178.1 (K), D184.1 (K), D188.1 (K), U52.25 (d)
/Sector3/Se: D137.1 (K), D149.1 (K), D154.1 (K), D159.1 (K), D169.1 (K), D179.1 (K), D189.1 (K), D193.1 (K), U52.2 (e)
/Sector3/Sf: D138.1 (K), D144.1 (K), D150.1 (K), D160.1 (K), D170.1 (K), D180.1 (K), D190.1 (K), D194.1 (K), U52.24 (f)
/Sector3/Sg: D139.1 (K), D151.1 (K), D161.1 (K), D163.1 (K), D171.1 (K), D181.1 (K), D191.1 (K), U52.26 (g)
/Sector3/dp: D140.1 (K), D152.1 (K), D162.1 (K), D164.1 (K), D172.1 (K), D182.1 (K), D192.1 (K), U52.4 (dp)
/Sector4/LD1: D195.2 (A), D196.2 (A), D197.2 (A), D198.2 (A), D199.2 (A), D200.2 (A), D201.2 (A), D202.2 (A), U53.15 (d1)
/Sector4/LD2: D207.2 (A), D208.2 (A), D209.2 (A), D210.2 (A), D211.2 (A), D212.2 (A), D213.2 (A), D214.2 (A), U53.16 (d2)
/Sector4/LD3: D217.2 (A), D218.2 (A), D219.2 (A), D220.2 (A), D221.2 (A), D222.2 (A), D223.2 (A), D224.2 (A), U53.23 (d3)
/Sector4/LD4: D227.2 (A), D228.2 (A), D229.2 (A), D230.2 (A), D231.2 (A), D232.2 (A), D233.2 (A), D234.2 (A), U53.20 (d4)
/Sector4/LD5: D237.2 (A), D238.2 (A), D239.2 (A), D240.2 (A), D241.2 (A), D242.2 (A), D243.2 (A), D244.2 (A), U53.17 (d5)
/Sector4/LD6: D247.2 (A), D248.2 (A), D249.2 (A), D250.2 (A), D251.2 (A), D252.2 (A), D253.2 (A), D254.2 (A), U53.22 (d6)
/Sector4/LD7: D203.2 (A), D204.2 (A), D205.2 (A), D206.2 (A), D215.2 (A), D216.2 (A), D225.2 (A), D226.2 (A), U53.21 (d7)
/Sector4/LD8: D235.2 (A), D236.2 (A), D245.2 (A), D246.2 (A), D255.2 (A), D256.2 (A), U53.18 (d8)
/Sector4/Sa: D195.1 (K), D205.1 (K), D207.1 (K), D217.1 (K), D227.1 (K), D235.1 (K), D237.1 (K), D247.1 (K), U53.27 (a)
/Sector4/Sb: D196.1 (K), D203.1 (K), D208.1 (K), D218.1 (K), D228.1 (K), D236.1 (K), D238.1 (K), D248.1 (K), U53.3 (b)
/Sector4/Sc: D197.1 (K), D204.1 (K), D209.1 (K), D219.1 (K), D229.1 (K), D239.1 (K), D245.1 (K), D249.1 (K), U53.1 (c)
/Sector4/Sd: D198.1 (K), D210.1 (K), D215.1 (K), D220.1 (K), D230.1 (K), D240.1 (K), D246.1 (K), D250.1 (K), U53.25 (d)
/Sector4/Se: D199.1 (K), D211.1 (K), D216.1 (K), D221.1 (K), D231.1 (K), D241.1 (K), D251.1 (K), D255.1 (K), U53.2 (e)
/Sector4/Sf: D200.1 (K), D206.1 (K), D212.1 (K), D222.1 (K), D232.1 (K), D242.1 (K), D252.1 (K), D256.1 (K), U53.24 (f)
/Sector4/Sg: D201.1 (K), D213.1 (K), D223.1 (K), D225.1 (K), D233.1 (K), D243.1 (K), D253.1 (K), U53.26 (g)
/Sector4/dp: D202.1 (K), D214.1 (K), D224.1 (K), D226.1 (K), D234.1 (K), D244.1 (K), D254.1 (K), U53.4 (dp)
/Sector5/LD1: D257.2 (A), D258.2 (A), D259.2 (A), D260.2 (A), D261.2 (A), D262.2 (A), D263.2 (A), D264.2 (A), U54.15 (d1)
/Sector5/LD2: D269.2 (A), D270.2 (A), D271.2 (A), D272.2 (A), D273.2 (A), D274.2 (A), D275.2 (A), D276.2 (A), U54.16 (d2)
/Sector5/LD3: D279.2 (A), D280.2 (A), D281.2 (A), D282.2 (A), D283.2 (A), D284.2 (A), D285.2 (A), D286.2 (A), U54.23 (d3)
/Sector5/LD4: D289.2 (A), D290.2 (A), D291.2 (A), D292.2 (A), D293.2 (A), D294.2 (A), D295.2 (A), D296.2 (A), U54.20 (d4)
/Sector5/LD5: D299.2 (A), D300.2 (A), D301.2 (A), D302.2 (A), D303.2 (A), D304.2 (A), D305.2 (A), D306.2 (A), U54.17 (d5)
/Sector5/LD6: D309.2 (A), D310.2 (A), D311.2 (A), D312.2 (A), D313.2 (A), D314.2 (A), D315.2 (A), D316.2 (A), U54.22 (d6)
/Sector5/LD7: D265.2 (A), D266.2 (A), D267.2 (A), D268.2 (A), D277.2 (A), D278.2 (A), D287.2 (A), D288.2 (A), U54.21 (d7)
/Sector5/LD8: D297.2 (A), D298.2 (A), D307.2 (A), D308.2 (A), D317.2 (A), D318.2 (A), U54.18 (d8)
/Sector5/Sa: D257.1 (K), D267.1 (K), D269.1 (K), D279.1 (K), D289.1 (K), D297.1 (K), D299.1 (K), D309.1 (K), U54.27 (a)
/Sector5/Sb: D258.1 (K), D265.1 (K), D270.1 (K), D280.1 (K), D290.1 (K), D298.1 (K), D300.1 (K), D310.1 (K), U54.3 (b)
/Sector5/Sc: D259.1 (K), D266.1 (K), D271.1 (K), D281.1 (K), D291.1 (K), D301.1 (K), D307.1 (K), D311.1 (K), U54.1 (c)
/Sector5/Sd: D260.1 (K), D272.1 (K), D277.1 (K), D282.1 (K), D292.1 (K), D302.1 (K), D308.1 (K), D312.1 (K), U54.25 (d)
/Sector5/Se: D261.1 (K), D273.1 (K), D278.1 (K), D283.1 (K), D293.1 (K), D303.1 (K), D313.1 (K), D317.1 (K), U54.2 (e)
/Sector5/Sf: D262.1 (K), D268.1 (K), D274.1 (K), D284.1 (K), D294.1 (K), D304.1 (K), D314.1 (K), D318.1 (K), U54.24 (f)
/Sector5/Sg: D263.1 (K), D275.1 (K), D285.1 (K), D287.1 (K), D295.1 (K), D305.1 (K), D315.1 (K), U54.26 (g)
/Sector5/dp: D264.1 (K), D276.1 (K), D286.1 (K), D288.1 (K), D296.1 (K), D306.1 (K), D316.1 (K), U54.4 (dp)
/Sector6/LD1: D319.2 (A), D320.2 (A), D321.2 (A), D322.2 (A), D323.2 (A), D324.2 (A), D325.2 (A), D326.2 (A), U55.15 (d1)
/Sector6/LD2: D331.2 (A), D332.2 (A), D333.2 (A), D334.2 (A), D335.2 (A), D336.2 (A), D337.2 (A), D338.2 (A), U55.16 (d2)
/Sector6/LD3: D341.2 (A), D342.2 (A), D343.2 (A), D344.2 (A), D345.2 (A), D346.2 (A), D347.2 (A), D348.2 (A), U55.23 (d3)
/Sector6/LD4: D351.2 (A), D352.2 (A), D353.2 (A), D354.2 (A), D355.2 (A), D356.2 (A), D357.2 (A), D358.2 (A), U55.20 (d4)
/Sector6/LD5: D361.2 (A), D362.2 (A), D363.2 (A), D364.2 (A), D365.2 (A), D366.2 (A), D367.2 (A), D368.2 (A), U55.17 (d5)
/Sector6/LD6: D371.2 (A), D372.2 (A), D373.2 (A), D374.2 (A), D375.2 (A), D376.2 (A), D377.2 (A), D378.2 (A), U55.22 (d6)
/Sector6/LD7: D327.2 (A), D328.2 (A), D329.2 (A), D330.2 (A), D339.2 (A), D340.2 (A), D349.2 (A), D350.2 (A), U55.21 (d7)
/Sector6/LD8: D359.2 (A), D360.2 (A), D369.2 (A), D370.2 (A), D379.2 (A), D380.2 (A), U55.18 (d8)
/Sector6/Sa: D319.1 (K), D329.1 (K), D331.1 (K), D341.1 (K), D351.1 (K), D359.1 (K), D361.1 (K), D371.1 (K), U55.27 (a)
/Sector6/Sb: D320.1 (K), D327.1 (K), D332.1 (K), D342.1 (K), D352.1 (K), D360.1 (K), D362.1 (K), D372.1 (K), U55.3 (b)
/Sector6/Sc: D321.1 (K), D328.1 (K), D333.1 (K), D343.1 (K), D353.1 (K), D363.1 (K), D369.1 (K), D373.1 (K), U55.1 (c)
/Sector6/Sd: D322.1 (K), D334.1 (K), D339.1 (K), D344.1 (K), D354.1 (K), D364.1 (K), D370.1 (K), D374.1 (K), U55.25 (d)
/Sector6/Se: D323.1 (K), D335.1 (K), D340.1 (K), D345.1 (K), D355.1 (K), D365.1 (K), D375.1 (K), D379.1 (K), U55.2 (e)
/Sector6/Sf: D324.1 (K), D330.1 (K), D336.1 (K), D346.1 (K), D356.1 (K), D366.1 (K), D376.1 (K), D380.1 (K), U55.24 (f)
/Sector6/Sg: D325.1 (K), D337.1 (K), D347.1 (K), D349.1 (K), D357.1 (K), D367.1 (K), D377.1 (K), U55.26 (g)
/Sector6/dp: D326.1 (K), D338.1 (K), D348.1 (K), D350.1 (K), D358.1 (K), D368.1 (K), D378.1 (K), U55.4 (dp)
/~WR1: U51.8 (nWR)
/~WR2: U52.8 (nWR)
/~WR3: U53.8 (nWR)
/~WR4: U54.8 (nWR)
/~WR5: U55.8 (nWR)
GND: U51.28 (GND), U52.28 (GND), U53.28 (GND), U54.28 (GND), U55.28 (GND); also elsewhere on the board
VCC: U51.19 (V+), U52.19 (V+), U53.19 (V+), U54.19 (V+), U55.19 (V+); also elsewhere on the board

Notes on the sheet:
Ring 2 - 5mm
Ring 3 - 1206
Ring 4 - 1206
Ring 7 - 1206
Ring 6 - 1206
Ring 5 - 1206
Ring 1 - 3mm

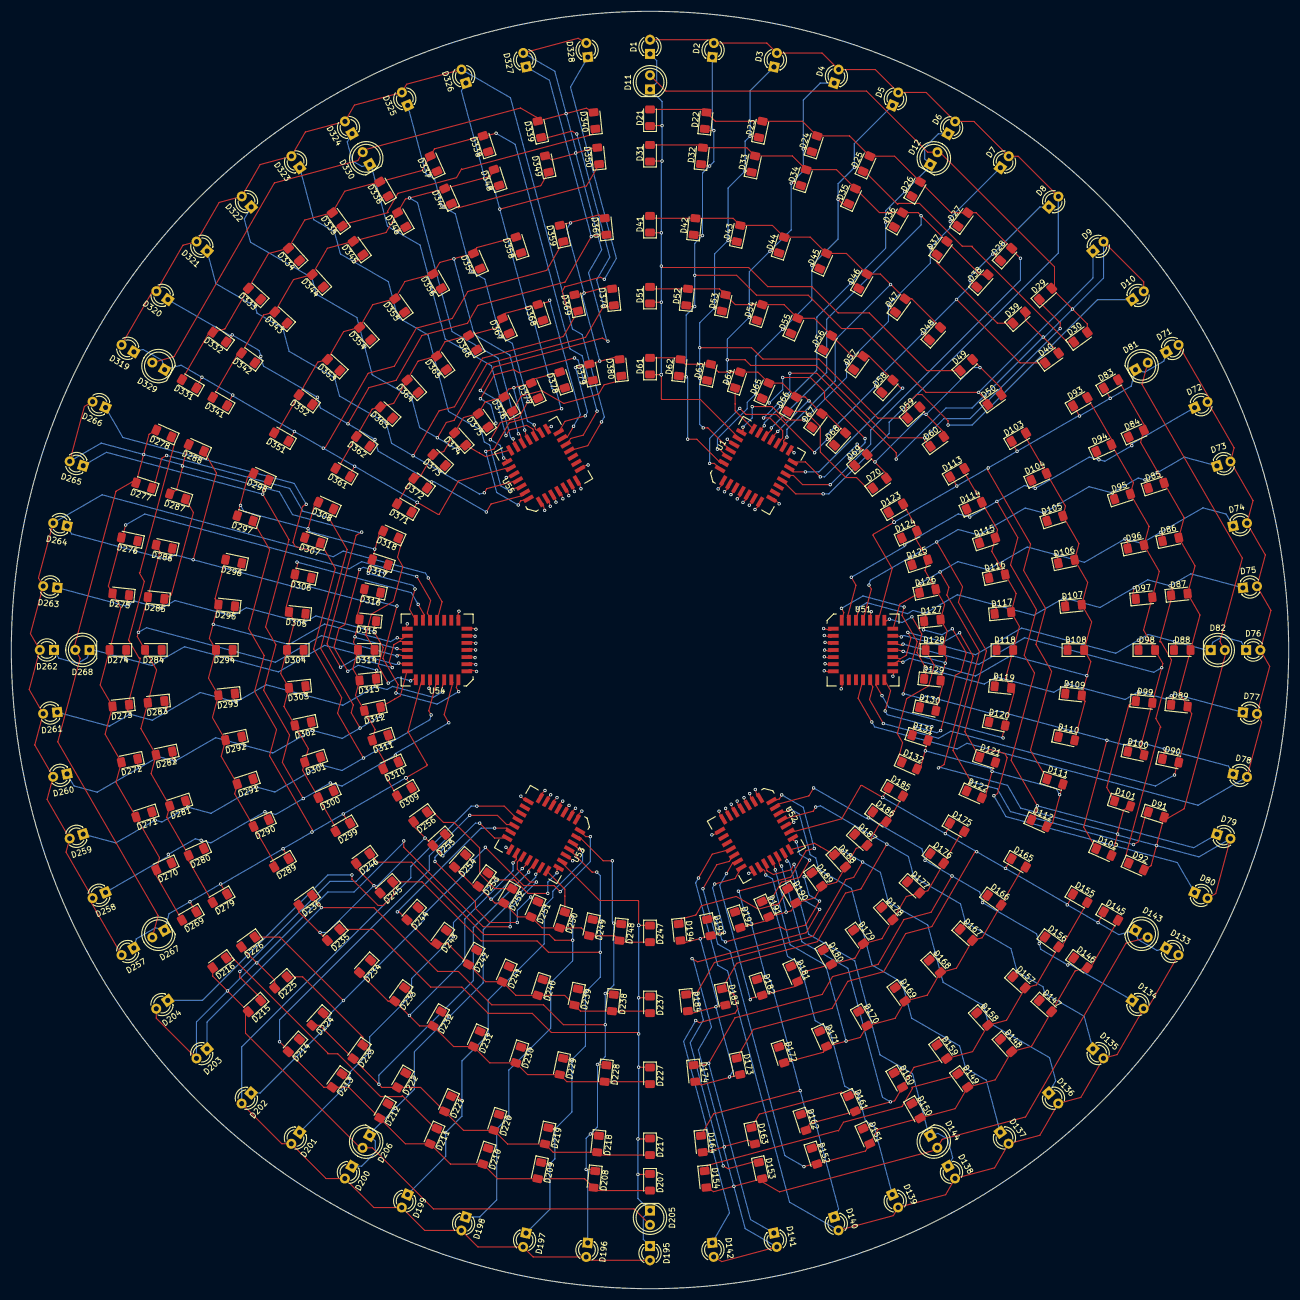
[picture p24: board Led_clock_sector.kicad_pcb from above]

Board: 2 copper layers, 228.6 x 228.6 mm, 378 parts (0 on the bottom side), 107 nets.

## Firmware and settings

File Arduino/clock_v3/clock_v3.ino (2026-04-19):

//
// Clock display driven by serial port
// Clock runs on it's own but without setting pins
//
// Expect 1200 baud time messages of the format [hh:mm:ss] to set
//

// #define SERIAL_DEBUG

#include <Arduino.h>
#include <string.h>

#include "led_map.h"

// default time at power-up (somewhat random!)
static unsigned t_hr = 11;
static unsigned t_min = 55;
static unsigned t_sec = 50;

// pins for setting the time
const int set_hr = 12;
const int set_min = 11;

#define TIMER_HZ 1000000L

static char buff[12];
#define BSIZ (sizeof(buff))

volatile uint32_t interruptCounter = 0;
hw_timer_t* timer = NULL;

// ISR function
void IRAM_ATTR onTimer() {
  interruptCounter++;
}


// display mapping for 1/6 sectors in dring[]
//
// bit
//   6 | w  w  w  w  w  w  w  w  w  w
//   5 | R              R
//   4 | G  G  G  G  G  G  G  G  G  G
//   3 | G  G  G  G  G  G  G  G  G  G
//   2 | B  B  B  B  B  B  B  B  B  B
//   1 | B  B  B  B  B  B  B  B  B  B
//   0 | B  B  B  B  B  B  B  B  B  B
//     +------------------------------
//pos    0  1  2  3  4  5  6  7  8  9
//
uint8_t dring[LED_NSEC][LED_NPOS];   // ring data for 6 sectors, 10 positions
uint8_t dled[8];	   // 7218 data for one sector

// Arduino pin numbers for 7218 WR for each sector
const int sec_wr[LED_NSEC] = { 2, 3, 4, 5, 6, 7};

// constant arrays with all LEDs lit and all blanked (note: D.P. is inverted)
static const uint8_t led_blank[] = { 0x80, 0x80, 0x80, 0x80, 0x80, 0x80, 0x80, 0x80};
static const uint8_t led_light[] = { 0x7f, 0x7f, 0x7f, 0x7f, 0x7f, 0x7f, 0x7f, 0x7f };

// Arduino pin numbers for 7218 data
const int LED_D0_PIN = A0;
const int LED_D1_PIN = A1;
const int LED_D2_PIN = A2;
const int LED_D3_PIN = A3;
const int LED_D4_PIN = A4;
const int LED_D5_PIN = A5;
const int LED_D6_PIN = A6;
const int LED_D7_PIN = A7;

// Arduino pin number for 7218 MODE
const int LED_MODE = 8;

// assert a data byte on the 7218 data bus
void led_data( uint8_t d) {
  digitalWrite( LED_D0_PIN, d & _BV(0)); // d
  digitalWrite( LED_D1_PIN, d & _BV(1)); // f
  digitalWrite( LED_D2_PIN, d & _BV(2)); // g
  digitalWrite( LED_D3_PIN, d & _BV(3)); // e
  digitalWrite( LED_D4_PIN, d & _BV(4)); // c
  digitalWrite( LED_D5_PIN, d & _BV(5)); // b
  digitalWrite( LED_D6_PIN, d & _BV(6)); // a
  digitalWrite( LED_D7_PIN, d & _BV(7)); // a  
}

// perform a write cycle to the 7218 with specified mode and sector
void led_write( int sec, uint8_t mode, uint8_t d) {
  digitalWrite( LED_MODE, mode);
  led_data( d);
  digitalWrite( sec_wr[sec], LOW);
  digitalWrite( sec_wr[sec], HIGH);
}

// 7218 commands
const uint8_t dpyblk = 0;	// blank the display
const uint8_t dpymod = 0xb0;	// no decode, data coming, not blanked
const uint8_t dpyhex = 0xd0;	// hex decode, data coming, not blanked

// update a 7218 from the specified data
void do7218( int sec, const uint8_t IX[8]) {
  led_write( sec, 1, dpymod);
  for( int i=0; i<8; i++)
    led_write( sec, 0, IX[i]);
}

// update the whole display from 60 bytes of data
void update_display( uint8_t dat[LED_NSEC][LED_NPOS]) {
  for( int i=0; i<LED_NSEC; i++) {
    update_sector( dat[i], dled);
    do7218( i, dled);
  }
}

#define wrap(n,m) (((n)+m)%m)


// display the time.  t_hr = 1..12  t_min = 0..59  t_sec = 0..59
//
void display_time( unsigned hr, unsigned min, unsigned sec, uint8_t (&dat)[LED_NSEC][LED_NPOS]) {
  uint8_t* pd = (uint8_t *)dat;
  int d_hr;
  // convert hour 1..12 to a display position 0..59
  // 12

  if( hr == 12)
    d_hr = min/12;
  else
    d_hr = hr*5 + (min/12);

  memset( dat, 0, sizeof(dat));

  // turn on Reds
  for( int i=0; i<12; i++)
    pd[i*5] |= 0x20;

  pd[sec] |= 0x40;		// set second bit in outer ring
  
  pd[ wrap(min,60) ] |= 0x18;		// set two bits in green rings
  pd[ wrap(min-1,60) ] |= 8;		// set adjacent bits
  pd[ wrap(min+1,60) ] |= 8;

  // hour is in range 1..12
  // convert hour, min to 0..59

  pd[ wrap(d_hr,60)] |= 7;			// set 3 bits in blue rings
  // set adjacent bits
  pd[ wrap(d_hr-2,60)] |= 1;
  pd[ wrap(d_hr+2,60)] |= 1;
  pd[ wrap(d_hr-1,60)] |= 3;
  pd[ wrap(d_hr+1,60)] |= 3;

  update_display( dat);
}


void setup() {
  pinMode( set_hr, INPUT_PULLUP);
  pinMode( set_min, INPUT_PULLUP);

  pinMode( LED_BUILTIN, OUTPUT);
  pinMode( LED_D0_PIN, OUTPUT);
  pinMode( LED_D1_PIN, OUTPUT);
  pinMode( LED_D2_PIN, OUTPUT);
  pinMode( LED_D3_PIN, OUTPUT);
  pinMode( LED_D4_PIN, OUTPUT);
  pinMode( LED_D5_PIN, OUTPUT);
  pinMode( LED_D6_PIN, OUTPUT);
  pinMode( LED_D7_PIN, OUTPUT);
  pinMode( LED_MODE, OUTPUT);
  for( int i=0; i<LED_NSEC; i++) {
    pinMode( sec_wr[i], OUTPUT);
    digitalWrite( sec_wr[i], HIGH);
  }
  // blank the display for all sectors
  for( int i=0; i<LED_NSEC; i++)
    do7218( i, led_blank);

  timer = timerBegin( 0, 80, true);	// 2kHz timer
  timerAttachInterrupt( timer, &onTimer, true);
  timerAlarmWrite( timer, TIMER_HZ, true);
  timerAlarmEnable( timer);

#ifdef SERIAL_DEBUG
  Serial.begin(115200);
  while( !Serial)
    ;
  delay(1000);
  Serial.println("clock test v3");
#endif  

  Serial1.begin(1200, SERIAL_8N1, D12, D11); // Rx on D12 (physical pin 15, LL corner)
}

void loop() {

  // display the time.  t_hr = 1..12  t_min = 0..59  t_sec = 0..59
  display_time( t_hr, t_min, t_sec, dring);

  // wait for 1Hz alarm interrupt
  while( 1) {
    if( interruptCounter) {
      interruptCounter = 0;
      break;
    }

    delay(10);

    // look for [hh:mm:ss]
    while( Serial1.available()) {

      char c = Serial1.read();

#ifdef SERIAL_DEBUG
      Serial.printf("Got %c\n", c);
#endif      

      memmove( buff, buff+1, BSIZ-2);
      buff[9] = c;
      if( buff[0] == '[' && buff[9] == ']') {
	buff[10] = '\0';
	t_hr = atoi( buff+1);
	t_min = atoi( buff+4);
	t_sec = atoi( buff+7);
	if( t_sec > 60)
	  t_sec = 0;
	if( t_min >= 60)
	  t_min = 0;
	while( t_hr > 12)
	  t_hr -= 12;
#ifdef SERIAL_DEBUG
	Serial.printf("Set from \"%s\" to (%d,%d,%d)\n", buff, t_hr, t_min, t_sec);
#endif      
      }
    }
  }

  // update the (12-hour) time
  t_sec++;
  if( t_sec >= 60) {
    t_sec = 0;
    t_min++;
    if( t_min >= 60) {
      t_min = 0;
      t_hr++;
      if( t_hr > 12)
	t_hr = 1;
    }
  }

  display_time( t_hr, t_min, t_sec, dring);
}

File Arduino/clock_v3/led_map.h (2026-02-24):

#include <stdint.h>

// display parameters
#define LED_NSEC 6
#define LED_NRING 7
#define LED_NPOS 10

// map LED locations in (ring, pos) to 7218 (byte, bit)
// where ring = 0..6
// and pos = 0..9 except in ring 5 where only 0, 5 are valid

// segment map:  7 6 5 4 3 2 1 0
//              dp a b c e g f d

typedef struct {
  int byt;
  int bit;
} a_tuple;

typedef a_tuple a_ring[LED_NPOS];

const a_ring led_map[LED_NRING] =
//POS:   0       1       2       3       4      5       6       7       8       9
  { { {5, 6}, {5, 5}, {5, 4}, {5, 0}, {5, 3}, {5, 1}, {5, 2}, {5, 7}, {7, 3}, {7, 1} },    // ring 0
    { {4, 6}, {4, 5}, {4, 4}, {4, 0}, {4, 3}, {4, 1}, {4, 2}, {4, 7}, {7, 4}, {7, 0} },    // ring 1
    { {3, 6}, {3, 5}, {3, 4}, {3, 0}, {3, 3}, {3, 1}, {3, 2}, {3, 7}, {7, 6}, {7, 5} },    // ring 2
    { {2, 6}, {2, 5}, {2, 4}, {2, 0}, {2, 3}, {2, 1}, {2, 2}, {2, 7}, {6, 2}, {6, 7} },    // ring 3
    { {1, 6}, {1, 5}, {1, 4}, {1, 0}, {1, 3}, {1, 1}, {1, 2}, {1, 7}, {6, 0}, {6, 3} },    // ring 4
    { {6, 6}, {9, 9}, {9, 9}, {9, 9}, {9, 9}, {6, 1}, {9, 9}, {9, 9}, {9, 9}, {9, 9} },    // ring 5
    { {0, 6}, {0, 5}, {0, 4}, {0, 0}, {0, 3}, {0, 1}, {0, 2}, {0, 7}, {6, 5}, {6, 4} } };  // ring 6

#define OVERWRITE_BIT(var, pos, val) \
    ( (var) = ( (var) & ~(1U << (pos)) ) | ( (!!(val)) << (pos) ) )

// update sector from array
void update_sector( uint8_t s[10], uint8_t d[8]) {
  // set up LED data
  for( int ring=0; ring<LED_NRING; ring++) {
    //    printf("Ring %d:\n", ring);
    for( int pos=0; pos<LED_NPOS; pos++) {
      int byt = led_map[ring][pos].byt;
      int bit = led_map[ring][pos].bit;
      //      printf( "  pos %d byt=%d seg=%c\n", pos, byt, segs[bit]);
      if( byt < 8 && bit < 8) {	// value 9 is null
	int val = !!(s[pos] & (1<<ring));
	if( bit == 7)		/* 7218 decimal point is inverted */
	  OVERWRITE_BIT( d[byt], bit, !val);
	else
	  OVERWRITE_BIT( d[byt], bit, val);
      }
    }
  }
}

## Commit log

2026-01-19 Starting on PCB
    [LED_clock.kicad_pcb, LED_clock.kicad_sch]
2026-01-20 initial placement
    [LED_clock.kicad_pcb, LED_clock.kicad_sch]
2026-01-20 Split into two boards
    [LED_clock_display.kicad_pcb, LED_clock_display.kicad_sch, LED_clock_logic.kicad_pcb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]
2026-01-20 adding Z80
    [LED_clock_logic.kicad_pcb, LED_clock_logic.kicad_sch]
2026-01-21 tentative placement
    [LED_clock-B_Cu.gbr, LED_clock-B_Mask.gbr, LED_clock-B_Silkscreen.gbr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]
2026-01-21 paused placement
    [LED_clock.kicad_pcb]
2026-01-21 working on sector-ized layout
    [Led_clock_sector.kicad_pcb, Led_clock_sector.kicad_sch, sector.kicad_sch]
2026-01-21 Sector-based layout
    [Led_clock_sector.kicad_pcb, Led_clock_sector.kicad_sch, sector.kicad_sch]
2026-01-22 rev 1?
    [Led_clock_sector-B_Cu.gbr, Led_clock_sector-B_Mask.gbr, Led_clock_sector-B_Silkscreen.gbr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]
2026-01-22 create proto sector
    [LED_proto_sector-B_Cu.gbr, LED_proto_sector-B_Mask.gbr, LED_proto_sector-B_Silkscreen.gbr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]
2026-01-23 prototype sector
    [LED_proto_sector-B_Cu.gbr, LED_proto_sector-B_Mask.gbr, LED_proto_sector-B_Silkscreen.gbr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]
2026-01-23 rearrange folders to purge history
    [LED_clock-B_Cu.gbr, LED_clock-B_Mask.gbr, LED_clock-B_Silkscreen.gbr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]
2026-02-04 mounting clip
    [plate.scad, plate.stl]
2026-02-18 control panel start
    [ControlPanelRTC-B_Cu.gbr, ControlPanelRTC-B_Mask.gbr, ControlPanelRTC-B_Silkscreen.gbr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]
2026-02-22 first test on pcb
2026-02-24 work on control panel
    [ControlPanelRTC.kicad_pcb, ControlPanelRTC.kicad_sch, c-1825910-6-c-3d.stp]
2026-02-24 MiniRTC board
    [HW-84 v7.step, SimpleRTC.kicad_pcb, SimpleRTC.kicad_sch]
2026-02-24 add buttons to simple RTC, change to ATTiny84
    [SimpleRTC.kicad_pcb, SimpleRTC.kicad_sch, c-1825910-6-c-3d.stp]
2026-02-25 Mounting plate with buttons
    [plate.scad, plate.stl]
2026-03-01 Clean up a bit
    [LED_clock-B_Cu.gbr, LED_clock-B_Mask.gbr, LED_clock-B_Silkscreen.gbr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]
2026-03-01 tweak code to reset seconds on 00 on minute set
    [clock_v2.ino]
2026-03-01 Fix? the clock code
    [PJ-082BH.STEP, PJ-082BH.step]
2026-03-26 As built SimpleRTC design
    [2026-03-15T160149.xlsx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]
2026-04-09 modifying layout for V2
    [SimpleRTC.kicad_pcb, SimpleRTC.kicad_sch]
2026-04-19 Updated mounting plate
    [plate2.scad, plate2.stl, test.stl]
2026-04-20 update setting firmware
    [plate2.scad, plate2.stl]
2026-04-20 Update the mounting plate
    [plate2.scad, plate2.stl]
